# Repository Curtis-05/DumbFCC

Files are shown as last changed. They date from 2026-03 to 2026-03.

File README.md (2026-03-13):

<p align="center" width="100%">
  
</p>

<h1 align="center">Dumb FCC</h1>

<p align="center" width="100%">
  <a href="https://github.com/Curtis-05/DumbFCC/actions/workflows/ci.yaml">
    
  </a>
</p>

<p align="center" width="100%">
    
</p>

***

<p align="center">
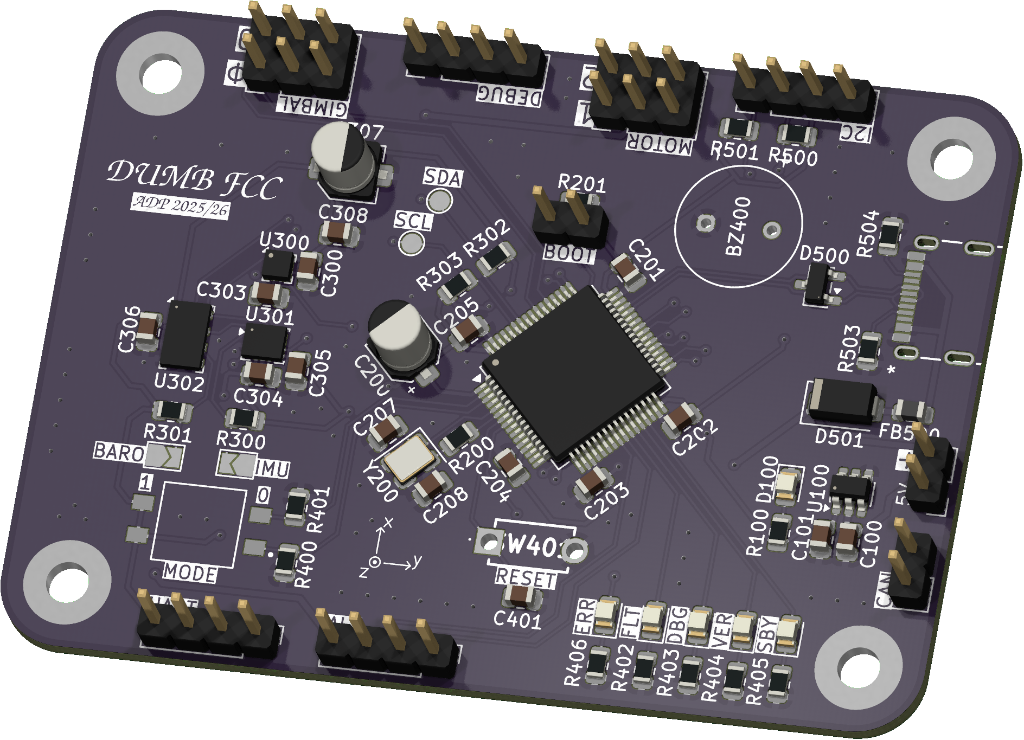
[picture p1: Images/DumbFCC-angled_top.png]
3D Top Angled
  
&nbsp; &nbsp; &nbsp; &nbsp;
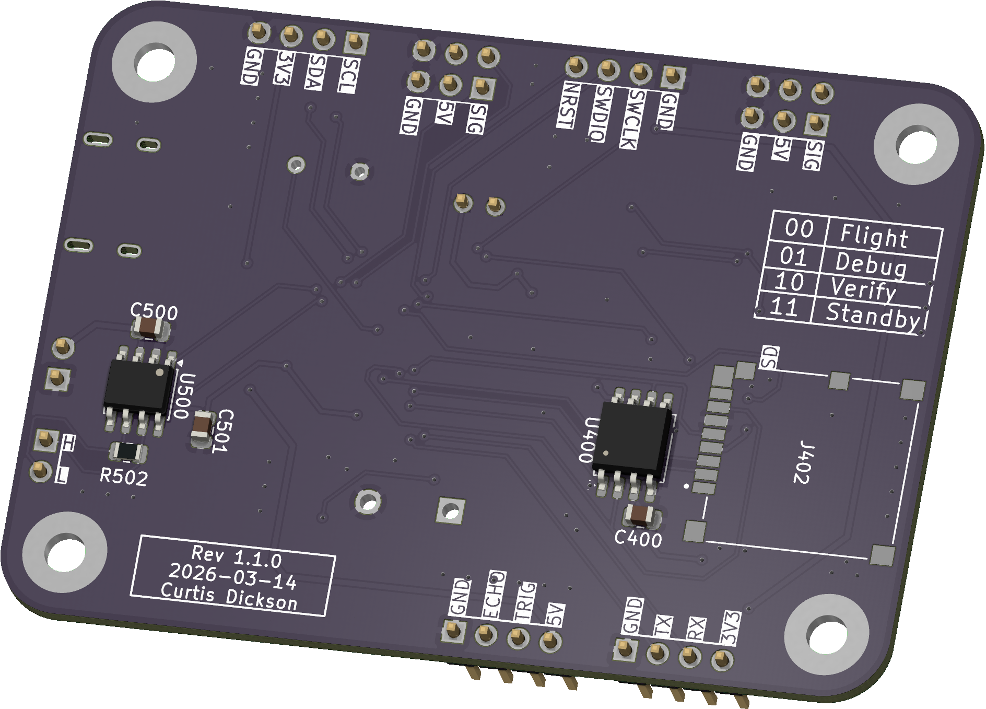
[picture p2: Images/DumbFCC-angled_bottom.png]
3D Bottom Angled
  
</p>

***

## SPECIFICATIONS

| Parameter | Value | 
| --- | --- |
| Dimensions | 70.0 × 50.0 mm |

***

## DIRECTORY STRUCTURE

    .
    ├─ Computations       # Misc calculations
    ├─ HTML               # HTML files for generated webpage
    ├─ Images             # Pictures and renders
    │
    ├─ kibot_resources    # External resources for KiBot
    │  ├─ colors          # Color theme for KiCad
    │  ├─ fonts           # Fonts used in the project
    │  ├─ scripts         # External scripts used with KiBot
    │  └─ templates       # Templates for KiBot generated reports
    │
    ├─ kibot_yaml         # KiBot YAML config files
    ├─ KiRI               # KiRI (PCB diff viewer) files
    │
    ├─ lib                # KiCad footprint and symbol libraries
    │  ├─ 3d_models       # Component 3D models
    │  ├─ lib_fp          # Footprint libraries
    │  └─ lib_sym         # Symbol libraries
    │
    ├─ Logos              # Logos
    │
    ├─ Manufacturing      # Assembly and fabrication documents
    │  ├─ Assembly        # Assembly documents (BoM, pos, notes)
    │  │
    │  └─ Fabrication     # Fabrication documents (ZIP, notes)
    │     ├─ Drill Tables # CSV drill tables
    │     └─ Gerbers      # Gerbers
    │
    ├─ Report             # Reports for ERC/DRC
    ├─ Schematic          # PDF of schematic
    ├─ Templates          # Title block templates
    ├─ Testing
    │  └─ Testpoints      # Testpoints tables      
    │
    └─ Variants           # Outputs for assembly variants

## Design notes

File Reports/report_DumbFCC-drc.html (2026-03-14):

Logo

(https://github.com/INTI-CMNB/KiBot/) | DRC report for DumbFCC
| PCB: DumbFCC Revision: 1.1.0 Date: 2026-03-14T05:20:28+0000 KiCad Version: 9.0.7 | Errors: 0 Warnings: 76 Total: 76

Violations

Type | Description | Details
connection_width | Copper connection too narrow (board setup constraints minimum connection width 0.1500 mm; actual 0.1209 mm) (L1 (Sig, PWR)) | @(114.5 mm, 60.0 mm): Zone 'GND' [GND] on L1 (Sig, PWR), L4 (Sig, PWR) and 2 more, priority 0
connection_width | Copper connection too narrow (board setup constraints minimum connection width 0.1500 mm; actual 0.1338 mm) (L1 (Sig, PWR)) | @(114.5 mm, 60.0 mm): Zone 'GND' [GND] on L1 (Sig, PWR), L4 (Sig, PWR) and 2 more, priority 0
connection_width | Copper connection too narrow (board setup constraints minimum connection width 0.1500 mm; actual 0.0480 mm) (L1 (Sig, PWR)) | @(114.5 mm, 60.0 mm): Zone 'GND' [GND] on L1 (Sig, PWR), L4 (Sig, PWR) and 2 more, priority 0
silk_edge_clearance | Silkscreen clipped by board edge | @(184.5 mm, 65.0 mm): Segment on Edge.Cuts @(184.161593 mm, 80.5974 mm): Segment of J506 on F.Silkscreen
silk_edge_clearance | Silkscreen clipped by board edge | @(184.5 mm, 65.0 mm): Segment on Edge.Cuts @(185.0052 mm, 71.4026 mm): Segment of J506 on F.Silkscreen
lib_footprint_mismatch | Footprint 'SOT-23-3' does not match copy in library 'Package_TO_SOT_SMD'. | @(171.3625 mm, 75.95 mm): Footprint D500
lib_footprint_mismatch | Footprint 'PinHeader_1x04_P2.54mm_Vertical' does not match copy in library 'Connector_PinHeader_2.54mm'. | @(134.81 mm, 108.0 mm): Footprint J501
lib_footprint_mismatch | Footprint 'C_0805_2012Metric' does not match copy in library 'Capacitor_SMD'. | @(141.3 mm, 90.9 mm): Footprint C207
lib_footprint_mismatch | Footprint 'C_0805_2012Metric' does not match copy in library 'Capacitor_SMD'. | @(122.2 mm, 85.0 mm): Footprint C306
lib_footprint_mismatch | Footprint 'PinHeader_2x03_P2.54mm_Vertical' does not match copy in library 'Connector_PinHeader_2.54mm'. | @(153.75 mm, 64.29 mm): Footprint J504
lib_footprint_mismatch | Footprint 'C_0805_2012Metric' does not match copy in library 'Capacitor_SMD'. | @(153.55 mm, 102.5 mm): Footprint C401
lib_footprint_mismatch | Footprint 'LED_0805_2012Metric' does not match copy in library 'LED_SMD'. | @(173.85 mm, 103.0 mm): Footprint D403
lib_footprint_mismatch | Footprint 'R_0805_2012Metric' does not match copy in library 'Resistor_SMD'. | @(176.0 mm, 80.5 mm): Footprint R503
lib_footprint_mismatch | Footprint 'R_0805_2012Metric' does not match copy in library 'Resistor_SMD'. | @(135.55 mm, 101.68 mm): Footprint R400
lib_footprint_mismatch | Footprint 'R_0805_2012Metric' does not match copy in library 'Resistor_SMD'. | @(173.85 mm, 106.9375 mm): Footprint R405
lib_footprint_mismatch | Footprint 'R_0805_2012Metric' does not match copy in library 'Resistor_SMD'. | @(163.3 mm, 64.5 mm): Footprint R501
lib_footprint_mismatch | Footprint 'Crystal_SMD_Abracon_ABM8G-4Pin_3.2x2.5mm' does not match copy in library 'Crystal'. | @(143.378858 mm, 92.823223 mm): Footprint Y200
lib_footprint_mismatch | Footprint 'LED_0805_2012Metric' does not match copy in library 'LED_SMD'. | @(167.14 mm, 103.0625 mm): Footprint D401
lib_footprint_mismatch | Footprint 'R_0805_2012Metric' does not match copy in library 'Resistor_SMD'. | @(135.56 mm, 97.32 mm): Footprint R401
lib_footprint_mismatch | Footprint 'LED_0805_2012Metric' does not match copy in library 'LED_SMD'. | @(171.8 mm, 91.7 mm): Footprint D100
lib_footprint_mismatch | Footprint 'PinHeader_1x04_P2.54mm_Vertical' does not match copy in library 'Connector_PinHeader_2.54mm'. | @(148.33 mm, 108.0 mm): Footprint J300
lib_footprint_mismatch | Footprint 'C_0805_2012Metric' does not match copy in library 'Capacitor_SMD'. | @(157.328249 mm, 93.171751 mm): Footprint C203
lib_footprint_mismatch | Footprint 'LED_0805_2012Metric' does not match copy in library 'LED_SMD'. | @(163.64 mm, 103.0625 mm): Footprint D400
lib_footprint_mismatch | Footprint 'C_0805_2012Metric' does not match copy in library 'Capacitor_SMD'. | @(133.8 mm, 86.8 mm): Footprint C305
lib_footprint_mismatch | Footprint 'R_0805_2012Metric' does not match copy in library 'Resistor_SMD'. | @(125.0 mm, 91.0 mm): Footprint R301
lib_footprint_mismatch | Footprint 'C_0805_2012Metric' does not match copy in library 'Capacitor_SMD'. | @(163.0 mm, 87.5 mm): Footprint C202
lib_footprint_mismatch | Footprint 'PinHeader_1x04_P2.54mm_Vertical' does not match copy in library 'Connector_PinHeader_2.54mm'. | @(164.19 mm, 61.75 mm): Footprint J502
lib_footprint_mismatch | Footprint 'C_0805_2012Metric' does not match copy in library 'Capacitor_SMD'. | @(133.3 mm, 79.0 mm): Footprint C300
lib_footprint_mismatch | Footprint 'R_0805_2012Metric' does not match copy in library 'Resistor_SMD'. | @(171.8 mm, 95.2625 mm): Footprint R100
lib_footprint_mismatch | Footprint 'PinHeader_1x02_P2.54mm_Vertical' does not match copy in library 'Connector_PinHeader_2.54mm'. | @(182.5 mm, 91.225 mm): Footprint J100
lib_footprint_mismatch | Footprint 'C_0805_2012Metric' does not match copy in library 'Capacitor_SMD'. | @(151.0 mm, 92.5 mm): Footprint C204
lib_footprint_mismatch | Footprint 'PinHeader_1x04_P2.54mm_Vertical' does not match copy in library 'Connector_PinHeader_2.54mm'. | @(139.21 mm, 61.75 mm): Footprint J500
lib_footprint_mismatch | Footprint 'SOT-23-6' does not match copy in library 'Package_TO_SOT_SMD'. | @(176.65 mm, 91.5375 mm): Footprint U100
lib_footprint_mismatch | Footprint 'C_0805_2012Metric' does not match copy in library 'Capacitor_SMD'. | @(131.1 mm, 87.5 mm): Footprint C304
lib_footprint_mismatch | Footprint 'R_0805_2012Metric' does not match copy in library 'Resistor_SMD'. | @(146.7 mm, 90.7 mm): Footprint R200
lib_footprint_mismatch | Footprint 'R_0805_2012Metric' does not match copy in library 'Resistor_SMD'. | @(167.7 mm, 64.5 mm): Footprint R500
lib_footprint_mismatch | Footprint 'R_0805_2012Metric' does not match copy in library 'Resistor_SMD'. | @(160.09 mm, 107.0 mm): Footprint R406
lib_footprint_mismatch | Footprint 'L_0805_2012Metric' does not match copy in library 'Inductor_SMD'. | @(180.1 mm, 85.0 mm): Footprint FB500
lib_footprint_mismatch | Footprint 'R_0805_2012Metric' does not match copy in library 'Resistor_SMD'. | @(167.1 mm, 107.0 mm): Footprint R403
lib_footprint_mismatch | Footprint 'C_0805_2012Metric' does not match copy in library 'Capacitor_SMD'. | @(146.0 mm, 82.5 mm): Footprint C205
lib_footprint_mismatch | Footprint 'R_0805_2012Metric' does not match copy in library 'Resistor_SMD'. | @(147.0 mm, 76.5 mm): Footprint R302
lib_footprint_mismatch | Footprint 'LED_0805_2012Metric' does not match copy in library 'LED_SMD'. | @(170.5 mm, 103.0625 mm): Footprint D402
lib_footprint_mismatch | Footprint 'R_0805_2012Metric' does not match copy in library 'Resistor_SMD'. | @(152.4125 mm, 71.5 mm): Footprint R201
lib_footprint_mismatch | Footprint 'C_0805_2012Metric' does not match copy in library 'Capacitor_SMD'. | @(175.1 mm, 95.4 mm): Footprint C101
lib_footprint_mismatch | Footprint 'C_0805_2012Metric' does not match copy in library 'Capacitor_SMD'. | @(177.1 mm, 95.4 mm): Footprint C100
lib_footprint_mismatch | Footprint 'C_0805_2012Metric' does not match copy in library 'Capacitor_SMD'. | @(145.4 mm, 94.8 mm): Footprint C208
lib_footprint_mismatch | Footprint 'LQFP-64_10x10mm_P0.5mm' does not match copy in library 'Package_QFP'. | @(154.5 mm, 85.0 mm): Footprint U200
lib_footprint_mismatch | Footprint 'C_0805_2012Metric' does not match copy in library 'Capacitor_SMD'. | @(130.6 mm, 81.3 mm): Footprint C303
lib_footprint_mismatch | Footprint 'R_0805_2012Metric' does not match copy in library 'Resistor_SMD'. | @(176.0 mm, 71.5 mm): Footprint R504
lib_footprint_mismatch | Footprint 'C_0805_2012Metric' does not match copy in library 'Capacitor_SMD'. | @(157.0 mm, 76.5 mm): Footprint C201
lib_footprint_mismatch | Footprint 'LED_0805_2012Metric' does not match copy in library 'LED_SMD'. | @(160.09 mm, 103.0625 mm): Footprint D404
lib_footprint_mismatch | Footprint 'LGA-14_3x2.5mm_P0.5mm_LayoutBorder3x4y' does not match copy in library 'Package_LGA'. | @(131.0 mm, 85.0 mm): Footprint U301
lib_footprint_mismatch | Footprint 'PinHeader_2x03_P2.54mm_Vertical' does not match copy in library 'Connector_PinHeader_2.54mm'. | @(127.46 mm, 64.29 mm): Footprint J505
lib_footprint_mismatch | Footprint 'R_0805_2012Metric' does not match copy in library 'Resistor_SMD'. | @(163.64 mm, 107.0 mm): Footprint R402
lib_footprint_mismatch | Footprint 'R_0805_2012Metric' does not match copy in library 'Resistor_SMD'. | @(144.5 mm, 79.0 mm): Footprint R303
lib_footprint_mismatch | Footprint 'PinHeader_1x02_P2.54mm_Vertical' does not match copy in library 'Connector_PinHeader_2.54mm'. | @(182.5 mm, 96.225 mm): Footprint J503
lib_footprint_mismatch | Footprint 'R_0805_2012Metric' does not match copy in library 'Resistor_SMD'. | @(170.5 mm, 107.0625 mm): Footprint R404
lib_footprint_mismatch | Footprint 'C_0805_2012Metric' does not match copy in library 'Capacitor_SMD'. | @(135.0 mm, 76.0 mm): Footprint C308
lib_footprint_mismatch | Footprint 'R_0805_2012Metric' does not match copy in library 'Resistor_SMD'. | @(130.5 mm, 91.0 mm): Footprint R300
lib_footprint_mismatch | Footprint 'SOIC-8_5.3x5.3mm_P1.27mm' does not match copy in library 'Package_SO'. | @(137.0 mm, 91.5 mm): Footprint U400
lib_footprint_mismatch | Footprint 'SOIC-8_3.9x4.9mm_P1.27mm' does not match copy in library 'Package_SO'. | @(175.905 mm, 91.475 mm): Footprint U500
lib_footprint_mismatch | Footprint 'R_0805_2012Metric' does not match copy in library 'Resistor_SMD'. | @(176.0 mm, 96.5 mm): Footprint R502
lib_footprint_mismatch | Footprint 'C_0805_2012Metric' does not match copy in library 'Capacitor_SMD'. | @(135.4 mm, 97.3 mm): Footprint C400
lib_footprint_mismatch | Footprint 'C_0805_2012Metric' does not match copy in library 'Capacitor_SMD'. | @(170.5 mm, 94.0 mm): Footprint C501
lib_footprint_mismatch | Footprint 'C_0805_2012Metric' does not match copy in library 'Capacitor_SMD'. | @(176.0 mm, 86.5 mm): Footprint C500
silk_over_copper | Silkscreen clipped by solder mask | @(129.9 mm, 78.4 mm): Segment of U300 on F.Silkscreen
silk_over_copper | Silkscreen clipped by solder mask | @(129.9 mm, 79.6 mm): Segment of U300 on F.Silkscreen
silk_over_copper | Silkscreen clipped by solder mask | @(129.9 mm, 80.1 mm): Segment of U300 on F.Silkscreen
silk_over_copper | Silkscreen clipped by solder mask | @(132.1 mm, 77.9 mm): Segment of U300 on F.Silkscreen
silk_over_copper | Silkscreen clipped by solder mask | @(132.1 mm, 78.4 mm): Segment of U300 on F.Silkscreen
silk_over_copper | Silkscreen clipped by solder mask | @(132.1 mm, 79.6 mm): Segment of U300 on F.Silkscreen
silk_over_copper | Silkscreen clipped by solder mask | @(178.1968 mm, 76.0 mm): Reference field of J506
silk_over_copper | Silkscreen clipped by solder mask | @(123.4225 mm, 87.7225 mm): Segment of U302 on F.Silkscreen
silk_over_copper | Silkscreen clipped by solder mask | @(126.7225 mm, 82.5225 mm): Segment of U302 on F.Silkscreen
silk_over_copper | Silkscreen clipped by solder mask | @(126.7225 mm, 87.2225 mm): Segment of U302 on F.Silkscreen
silk_over_copper | Silkscreen clipped by solder mask | @(153.55 mm, 98.3533 mm): Reference field of SW401

Generated by KiBot (https://github.com/INTI-CMNB/KiBot/) v1.8.6

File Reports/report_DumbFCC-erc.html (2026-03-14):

Logo

(https://github.com/INTI-CMNB/KiBot/) | ERC report for DumbFCC
| Schematic: DumbFCC Revision: 1.1.0 Date: 2026-03-14T05:20:26+0000 KiCad Version: 9.0.7 | Errors: 0 Warnings: 13 Total: 13

Sheet / (DumbFCC.kicad_sch)

Type | Description | Details
footprint_link_issues | The current configuration does not include the footprint library '5027740891'. | @(0.6223 mm, 0.7112 mm): Symbol J402 [5027740891]
lib_symbol_issues | The current configuration does not include the symbol library '5027740891' | @(0.6223 mm, 0.7112 mm): Symbol J402 [5027740891]
footprint_link_issues | The current configuration does not include the footprint library 'AI-1027-TWT-3V-R'. | @(1.1938 mm, 1.0922 mm): Symbol BZ400 [Buzzer]
footprint_link_issues | The current configuration does not include the footprint library 'DS04-254-1-02BK-SMT'. | @(1.6002 mm, 0.6096 mm): Symbol SW400 [SW_DIP_x02]
footprint_link_issues | The current configuration does not include the footprint library 'DTS-32N-V-B'. | @(1.5748 mm, 1.143 mm): Symbol SW401 [SW_Push]
footprint_link_issues | The current configuration does not include the footprint library '2171790001_MOL'. | @(1.7018 mm, 1.0922 mm): Symbol J506 [2171790001]
lib_symbol_issues | The current configuration does not include the symbol library '2026-01-15_13-06-23' | @(1.7018 mm, 1.0922 mm): Symbol J506 [2171790001]
lib_symbol_issues | The current configuration does not include the symbol library 'MCP2562T-E_SN' | @(2.2987 mm, 0.6223 mm): Symbol U500 [MCP2562T-E_SN]
footprint_link_issues | Footprint 'P25_DO-214AC_SMA' not found in library 'DO214AAC'. | @(2.3495 mm, 1.1557 mm): Symbol D501 [D_Schottky]
lib_symbol_issues | The current configuration does not include the symbol library 'ADP3330ARTZ3.3-RL7' | @(1.4351 mm, 0.9271 mm): Symbol U100 [ADP3330ARTZ3.3-RL7]
lib_symbol_mismatch | Symbol 'Crystal_GND23' doesn't match copy in library 'Device' | @(2.4638 mm, 0.889 mm): Symbol Y200 [Crystal_GND23]

Sheet /Project Architecture/Sensors/ (Sensors.kicad_sch)

Type | Description | Details
pin_to_pin | Pins of type Bidirectional and Power output are connected | @(1.1557 mm, 0.8001 mm): Symbol U301 Pin 2 [SDX, Bidirectional, Line] @(2.1082 mm, 1.0922 mm): Symbol J506 Pin B1/A12 [GND, Power output, Line]

Sheet /Project Architecture/Connections/ (Connections.kicad_sch)

Type | Description | Details
multiple_net_names | Both I2C_PERIPH_SCL and I2C_SCL are attached to the same items; I2C_PERIPH_SCL will be used in the netlist | @(1.3081 mm, 0.5715 mm): Label 'I2C_PERIPH_SCL' @(1.3081 mm, 0.5715 mm): Label 'I2C_SCL'

Generated by KiBot (https://github.com/INTI-CMNB/KiBot/) v1.8.6

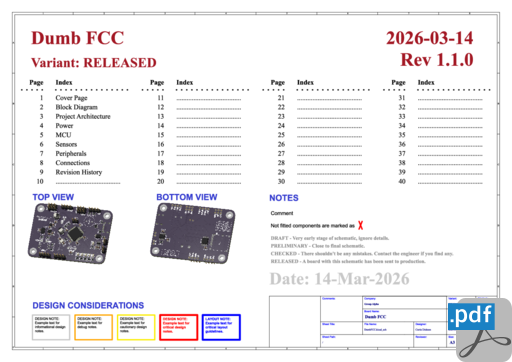
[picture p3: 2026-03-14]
HTML/images/cat_pdf_schematic_DumbFCC-schematic.png

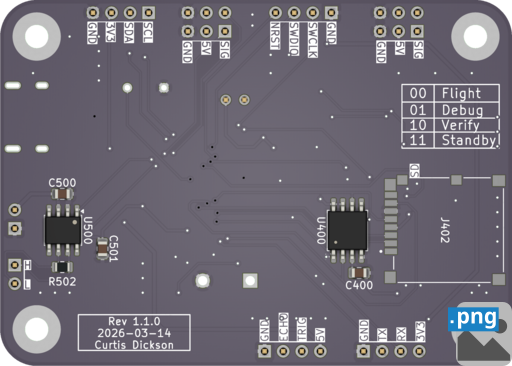
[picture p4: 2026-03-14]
HTML/images/cat_png_3d_viewer_bottom_DumbFCC-bottom.png

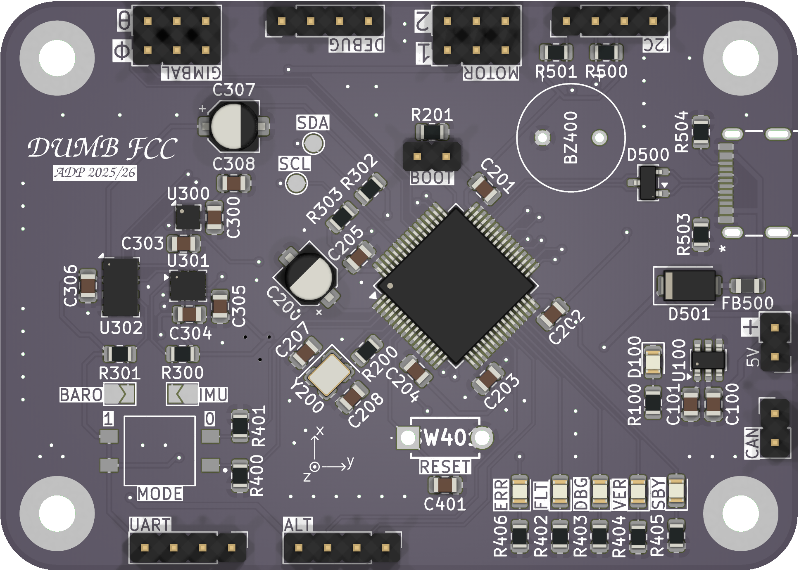
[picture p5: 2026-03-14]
Images/DumbFCC-top.png

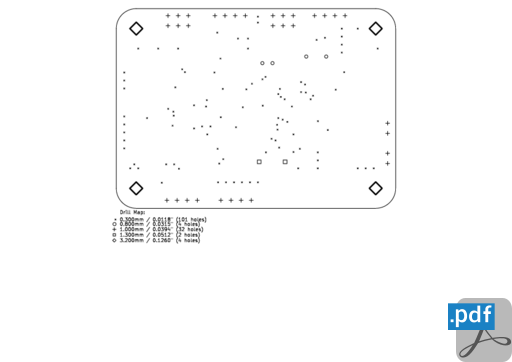
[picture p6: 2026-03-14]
HTML/images/cat_pdf_drill_map_DumbFCC-PTH_drill_map.png

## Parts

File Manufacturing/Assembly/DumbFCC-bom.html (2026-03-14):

 | Bill of Materials
 | Schematic: DumbFCC Variant: RELEASED Revision: 1.1.0 Date: 2025-01-12 KiCad Version: 9.0.7+1 | Component Groups: 33 Component Count: 70 (per PCB) Fitted Components: 70 (per PCB) Number of PCBs: 1 Total Components: 70 (for 1 PCBs)
Row | Quantity Per PCB | References | Value | Datasheet | Footprint | Description | Manufacturer | Manufacturer Part Number | Supplier Part Number
1 | 1 | BZ400 | Buzzer | ~ | XDCR_AI-1027-TWT-3V-R | Buzzer, polarized
2 | 2 | C207 C208 | 10p | ~ | C_0805_2012Metric | Unpolarized capacitor
3 | 14 | C201 C202 C203 C204 C205 C300 C304 C305 C306 C308 C400 C401 C500 C501 | 100n | ~ | C_0805_2012Metric | Unpolarized capacitor
4 | 1 | C303 | 220n | ~ | C_0805_2012Metric | Unpolarized capacitor
5 | 2 | C100 C101 | 470n | ~ | C_0805_2012Metric | Unpolarized capacitor
6 | 2 | C200 C307 | 10u | ~ | CP_Elec_4x5.7 | Polarized capacitor
7 | 1 | D401 | DBG | ~ | LED_0805_2012Metric | Light emitting diode
8 | 1 | D501 | D_Schottky | ~ | P25_DO-214AC_SMA | Schottky diode
9 | 1 | D404 | ERR | ~ | LED_0805_2012Metric | Light emitting diode
10 | 1 | D500 | ESDA6V1l-tp | https://www.st.com/resource/en/datasheet/esdal.pdf | SOT-23-3 | TVS Diode Array, 5.5V Standoff, 2 Channels, SOT23
11 | 1 | D400 | FLT | ~ | LED_0805_2012Metric | Light emitting diode
12 | 1 | D100 | PWR | ~ | LED_0805_2012Metric | Light emitting diode
13 | 1 | D403 | SBY | ~ | LED_0805_2012Metric | Light emitting diode
14 | 1 | D402 | VER | ~ | LED_0805_2012Metric | Light emitting diode
15 | 1 | FB500 | FerriteBead | ~ | L_0805_2012Metric | Ferrite bead
16 | 8 | J100 J300 J500 J501 J502 J503 J504 J505 | 5V Input | ~ | PinHeader_1x02_P2.54mm_Vertical | Generic connector, single row, 01x02, script generated Generic connector, single row, 01x04, script generated Generic connector, double row, 02x03, counter clockwise pin numbering scheme (similar to DIP package numbering), script generated (kicad-library-utils/schlib/autogen/connector/)
17 | 1 | J402 | SD port |  | MOLEX_5027740891
18 | 1 | J506 | USB C | https://www.molex.com/en-us/products/part-detail-pdf/2171790001?display=pdf | 2171790001_MOL
19 | 1 | R502 | 120 | ~ | R_0805_2012Metric | Resistor
20 | 6 | R100 R402 R403 R404 R405 R406 | 330 | ~ | R_0805_2012Metric | Resistor
21 | 1 | R200 | 620 | ~ | R_0805_2012Metric | Resistor
22 | 2 | R503 R504 | 5k1 | ~ | R_0805_2012Metric | Resistor
23 | 9 | R201 R300 R301 R302 R303 R400 R401 R500 R501 | 10k | ~ | R_0805_2012Metric | Resistor
24 | 1 | SW400 | Mode Switch | ~ | SW_DS04-254-1-02BK-SMT | 2x DIP Switch, Single Pole Single Throw (SPST) switch, small symbol
25 | 1 | SW401 | Reset | ~ | DTS32NVB | Push button switch, generic, two pins
26 | 1 | U100 | ADP3330ARTZ3.3-RL7 |  | SOT-23-6
27 | 1 | U300 | LIS2MDL | https://www.st.com/resource/en/datasheet/lis2mdl.pdf | LGA-12_2x2mm_P0.5mm | Ultra-low-power, 3-axis digital output magnetometer, LGA-12
28 | 1 | U301 | LSM6DSL | https://www.st.com/resource/en/datasheet/lsm6dsl.pdf | LGA-14_3x2.5mm_P0.5mm_LayoutBorder3x4y | I2C/SPI, iNEMO inertial module: always-on 3D accelerometer and 3D gyroscope, 1.71V to 3.6V VCC
29 | 1 | U500 | MCP2562T-E_SN | https://www.snapeda.com/parts/MCP2562T-E/SN/Microchip/datasheet/ | SOIC-8_3.9x4.9mm_P1.27mm |  | Microchip
30 | 1 | U302 | MS5607-02BA | https://www.te.com/commerce/DocumentDelivery/DDEController?Action=showdoc | LGA-8_3x5mm_P1.25mm | Barometric pressure sensor, 20cm resolution, 10 to 1200 mbar, I2C and SPI interface up to 20MHz, LGA-8
31 | 1 | U400 | SST26VF064BT-104I/SM | http://ww1.microchip.com/downloads/en/DeviceDoc/20005045C.pdf | SOIC-8_5.3x5.3mm_P1.27mm | 8-Mbit, 2.7 to 3.6V, SPI Flash Memory, SOIC-8
32 | 1 | U200 | STM32H573RIT6 | https://www.st.com/resource/en/datasheet/stm32h573ri.pdf | LQFP-64_10x10mm_P0.5mm | STMicroelectronics Arm Cortex-M33 MCU, 2048KB flash, 640KB RAM, 250 MHz, 1.62-3.6V, 49 GPIO, LQFP64
33 | 1 | Y200 | 25MHz | ~ | Crystal_SMD_Abracon_ABM8G-4Pin_3.2x2.5mm | Four pin crystal, GND on pins 2 and 3
Color reference for columns:
KiCad Fields (default)
Generated Fields
User Fields
Empty Fields

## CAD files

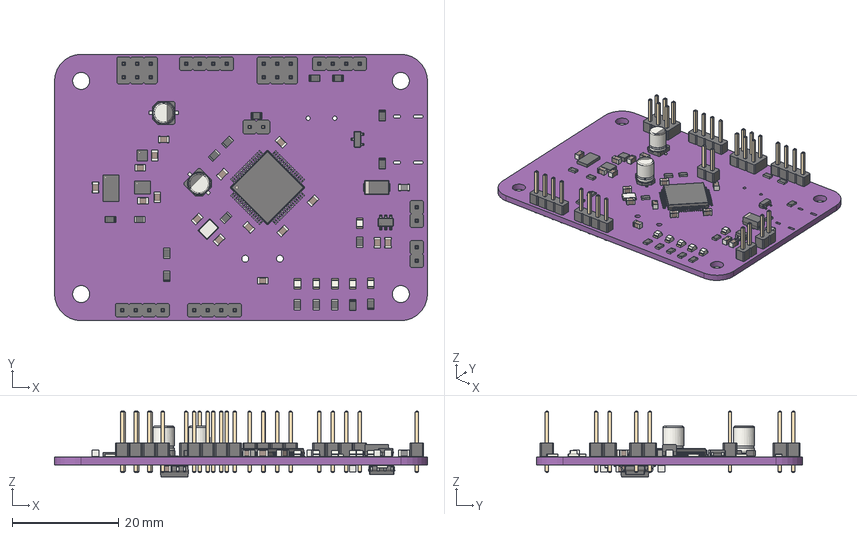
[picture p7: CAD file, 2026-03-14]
3D/DumbFCC.step
70.0 x 50.0 x 12.4 mm
SOT-23-3
PinHeader_1x04_P2.54mm_Vertical x 4
C_0805_2012Metric x 19
PinHeader_2x03_P2.54mm_Vertical x 2
D_SMA
LED_0805_2012Metric x 6
R_0805_2012Metric x 19
Crystal_SMD_Abracon_ABM8G-4Pin_3.2x2.5mm
LGA-12_2x2mm_P0.5mm
PinHeader_1x02_P2.54mm_Vertical x 3
SOT-23-6
L_0805_2012Metric
LGA-8_3x5mm_P1.25mm
LQFP-64_10x10mm_P0.5mm
LGA-14_3x2.5mm_P0.5mm_LayoutBorder3x4y
CP_Elec_4x5.7 x 2
SOIC-8_5.3x5.3mm_P1.27mm
SOIC-8_3.9x4.9mm_P1.27mm
kibot_xloh8s3n_PCB

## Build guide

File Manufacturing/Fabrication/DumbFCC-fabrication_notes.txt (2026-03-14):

FABRICATION NOTES (UNLESS OTHERWISE SPECIFIED)

1)	FABRICATE PER IPC-6012A CLASS 2.

2)	OUTLINE DEFINED IN SEPARATE GERBER FILE WITH
	"Edge_Cuts.GBR" SUFFIX.

	DIMENSIONS OF CIRCUMSIZED RECTANGLE SHOWN ON THIS
	DRAWING FOR REFERENCE ONLY.

3)	SEE SEPARATE DRILL FILES WITH ".DRL" SUFFIX 
	FOR HOLE LOCATIONS.

	SELECTED HOLE LOCATIONS SHOWN ON THIS DRAWING 
	FOR REFERENCE ONLY.

4)	SURFACE FINISH: HAL SNPB

5)	SOLDERMASK ON BOTH SIDES OF THE BOARD SHALL 
	BE LPI, COLOR PURPLE.

6)	SILK SCREEN LEGEND TO BE APPLIED PER LAYER 
	STACKUP USING WHITE NON-CONDUCTIVE EPOXY INK.

7)	ALL VIAS ARE TENTED ON BOTH SIDES UNLESS 
	SOLDERMASK OPENED IN GERBER.

8)	VENDOR SHOULD FOLLOW ROHS COMPLIANT PROCESS 
	AND Pb FREE FOR MANUFACTURING

9)	PCB MATERIAL REQUIREMENTS:

	A.	FLAMMABILITY RATING MUST MEET OR EXCEED 
		UL94V-0 REQUIREMENTS.
	B.	Tg 170 C OR EQUIVALENT.
	C.	EQUIVALENT MATERIAL SHALL BE RoHS COMPLIANT, 
		HALOGEN FREE AND APPROVED BY GROUP ALPHA.

10)	DESIGN GEOMETRY MINIMUM FEATURE SIZES:

	BOARD SIZE				70.000 × 50.000 mm
	BOARD THICKNESS		1.600 mm
	TRACE WIDTH			0.150 mm
	TRACE TO TRACE		0.150 mm
	MIN. HOLE (PTH)			0.300 mm
	MIN. HOLE (NPTH)		0.600 mm
	ANNULAR RING			0.150 mm
	COPPER TO HOLE		0.300 mm
	COPPER TO EDGE		0.500 mm
	HOLE TO HOLE			0.250 mm

11)	REFER TO IMPEDANCE TABLE FOR IMPEDANCE CONTROL REQUIREMENTS.

12)	CONFIRM SPACE WIDTHS AND SPACINGS.

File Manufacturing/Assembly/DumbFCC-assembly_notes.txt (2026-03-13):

ASSEMBLY NOTES (UNLESS OTHERWISE SPECIFIED)

1)	DO NOT POPULATE PARTS ARE MARKED WITH A RED CROSS.

2)	DO NOT POPULATE PARTS ARE NOT PRESENT IN THE BOM.

3)	IF CONFLICTING INFORMATION IS FOUND BETWEEN THE ASSEMBLY
	FILE AND BOM, BOM SHOULD BE USED AS THE MAIN SOURCE.

4)	CONFORMAL COATING IS NOT REQUIRED.

5)	DOT IDENTIFIES PIN #1 LOCATION AND DEVICE ORIENTATION
	WHEN VIEWED FROM THE TOP.

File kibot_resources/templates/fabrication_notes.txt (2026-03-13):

FABRICATION NOTES (UNLESS OTHERWISE SPECIFIED)

1)	FABRICATE PER IPC-6012A CLASS 2.

2)	OUTLINE DEFINED IN SEPARATE GERBER FILE WITH
	"Edge_Cuts.GBR" SUFFIX.

	DIMENSIONS OF CIRCUMSIZED RECTANGLE SHOWN ON THIS
	DRAWING FOR REFERENCE ONLY.

3)	SEE SEPARATE DRILL FILES WITH ".DRL" SUFFIX 
	FOR HOLE LOCATIONS.

	SELECTED HOLE LOCATIONS SHOWN ON THIS DRAWING 
	FOR REFERENCE ONLY.

4)	SURFACE FINISH: ${pcb_finish_cap}

5)	SOLDERMASK ON BOTH SIDES OF THE BOARD SHALL 
	BE LPI, COLOR ${solder_mask_color_text_cap}.

6)	SILK SCREEN LEGEND TO BE APPLIED PER LAYER 
	STACKUP USING ${silk_screen_color_text_cap} NON-CONDUCTIVE EPOXY INK.

7)	ALL VIAS ARE TENTED ON BOTH SIDES UNLESS 
	SOLDERMASK OPENED IN GERBER.

8)	VENDOR SHOULD FOLLOW ROHS COMPLIANT PROCESS 
	AND Pb FREE FOR MANUFACTURING

9)	PCB MATERIAL REQUIREMENTS:

	A.	FLAMMABILITY RATING MUST MEET OR EXCEED 
		UL94V-0 REQUIREMENTS.
	B.	Tg 170 C OR EQUIVALENT.
	C.	EQUIVALENT MATERIAL SHALL BE RoHS COMPLIANT, 
		HALOGEN FREE AND APPROVED BY ${COMPANY_cap}.

10)	DESIGN GEOMETRY MINIMUM FEATURE SIZES:

	BOARD SIZE				${bb_w_mm} × ${bb_h_mm} mm
	BOARD THICKNESS		${thickness_mm} mm
	TRACE WIDTH			${track_mm} mm
	TRACE TO TRACE		${clearance_mm} mm
	MIN. HOLE (PTH)			${drill_pth_real_mm} mm
	MIN. HOLE (NPTH)		${drill_npth_real_mm} mm
	ANNULAR RING			${oar_mm} mm
	COPPER TO HOLE		${c2h_mm} mm
	COPPER TO EDGE		${c2e_mm} mm
	HOLE TO HOLE			${h2h_mm} mm
#?stackup and impedance_controlled

#?stackup and impedance_controlled
11)	REFER TO IMPEDANCE TABLE FOR IMPEDANCE CONTROL REQUIREMENTS.
#?stackup and impedance_controlled

#?stackup and impedance_controlled
12)	CONFIRM SPACE WIDTHS AND SPACINGS.

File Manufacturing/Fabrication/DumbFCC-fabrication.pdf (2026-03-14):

# Top Fabrication (Scale 1:1)

# Dumb FCC Fabrication Document

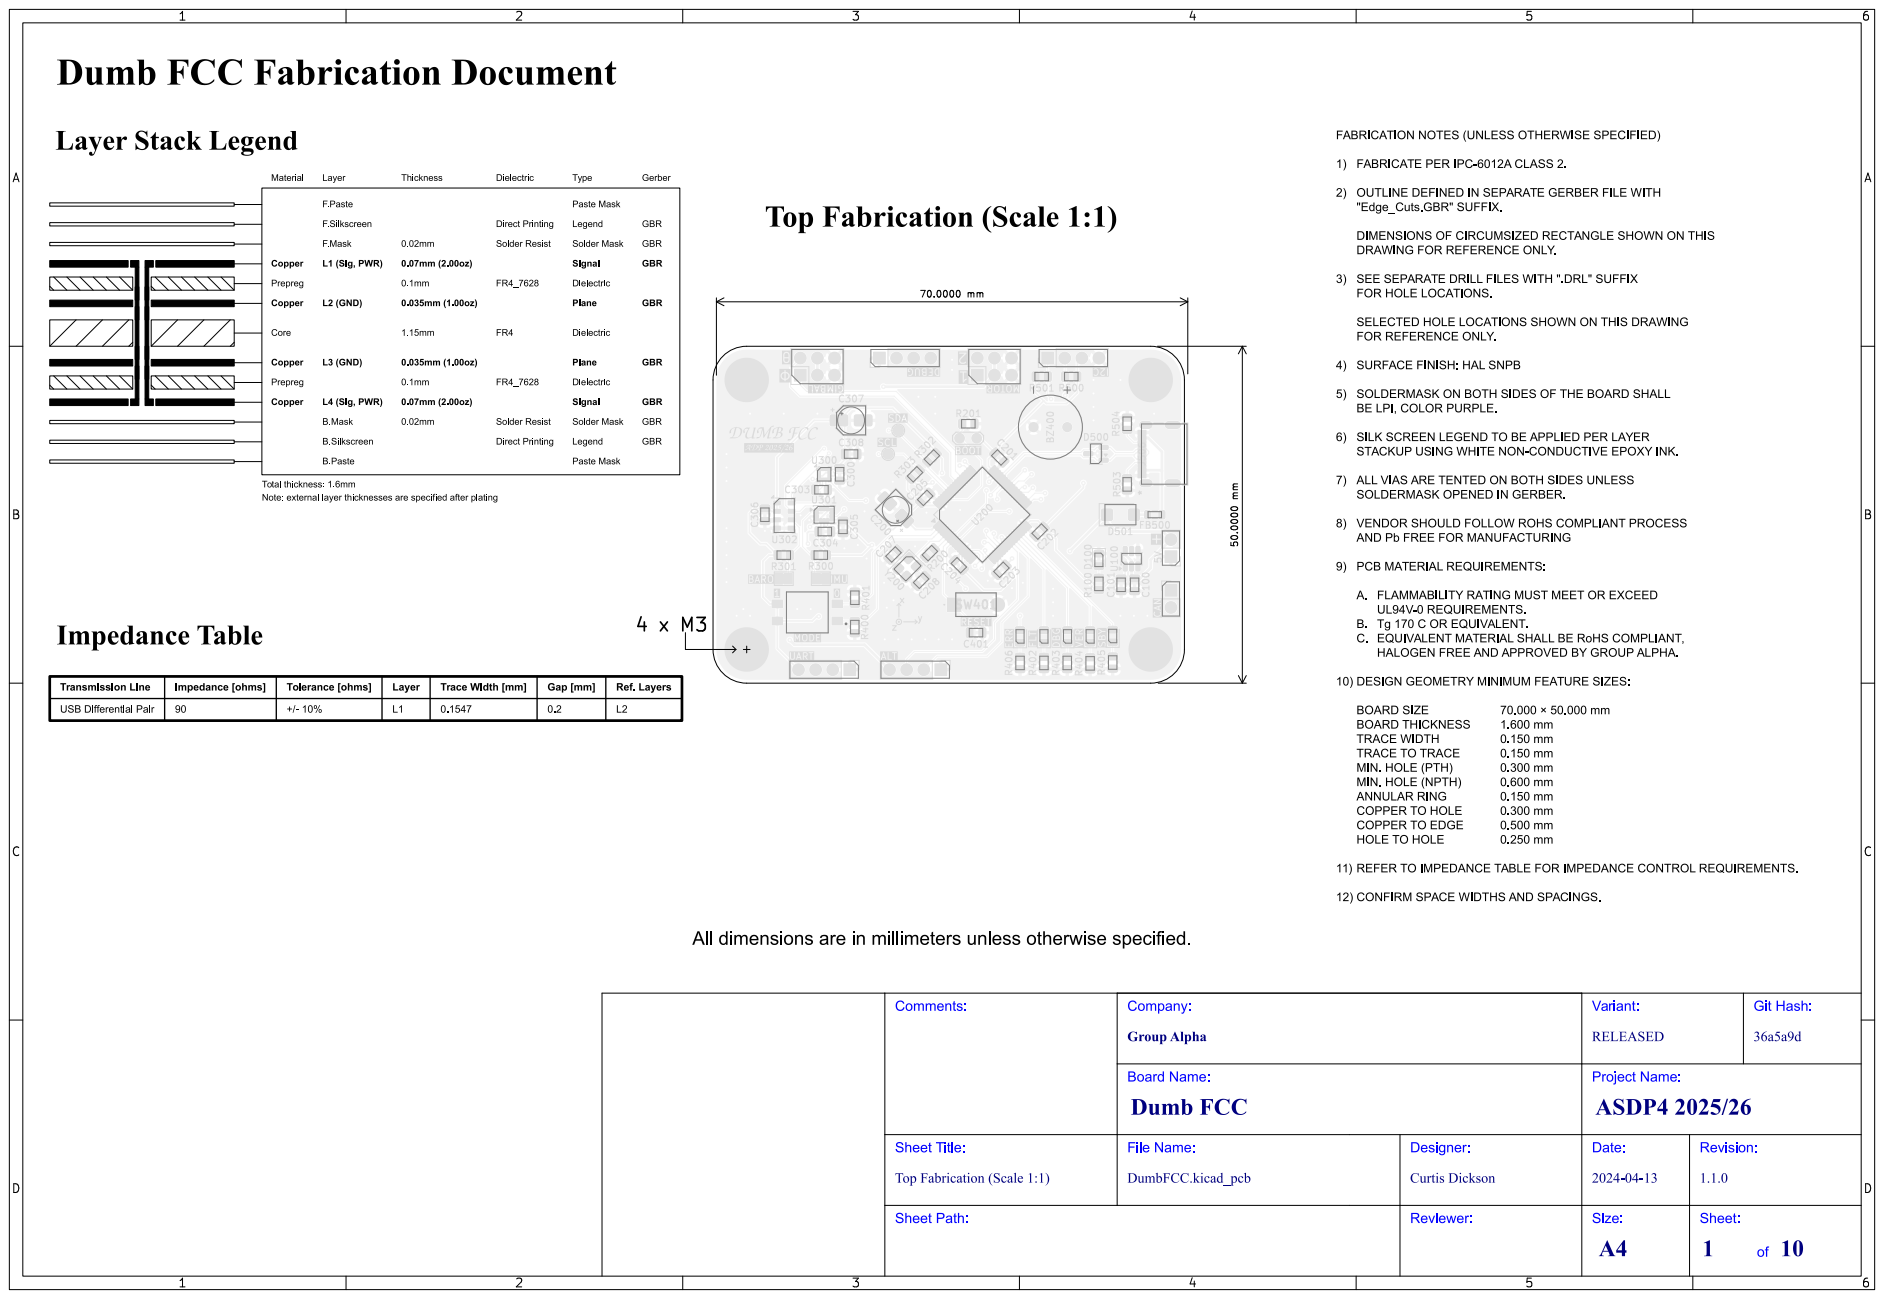
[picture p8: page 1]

# Bottom Fabrication (Scale 1:1)

# Dumb FCC Fabrication Document

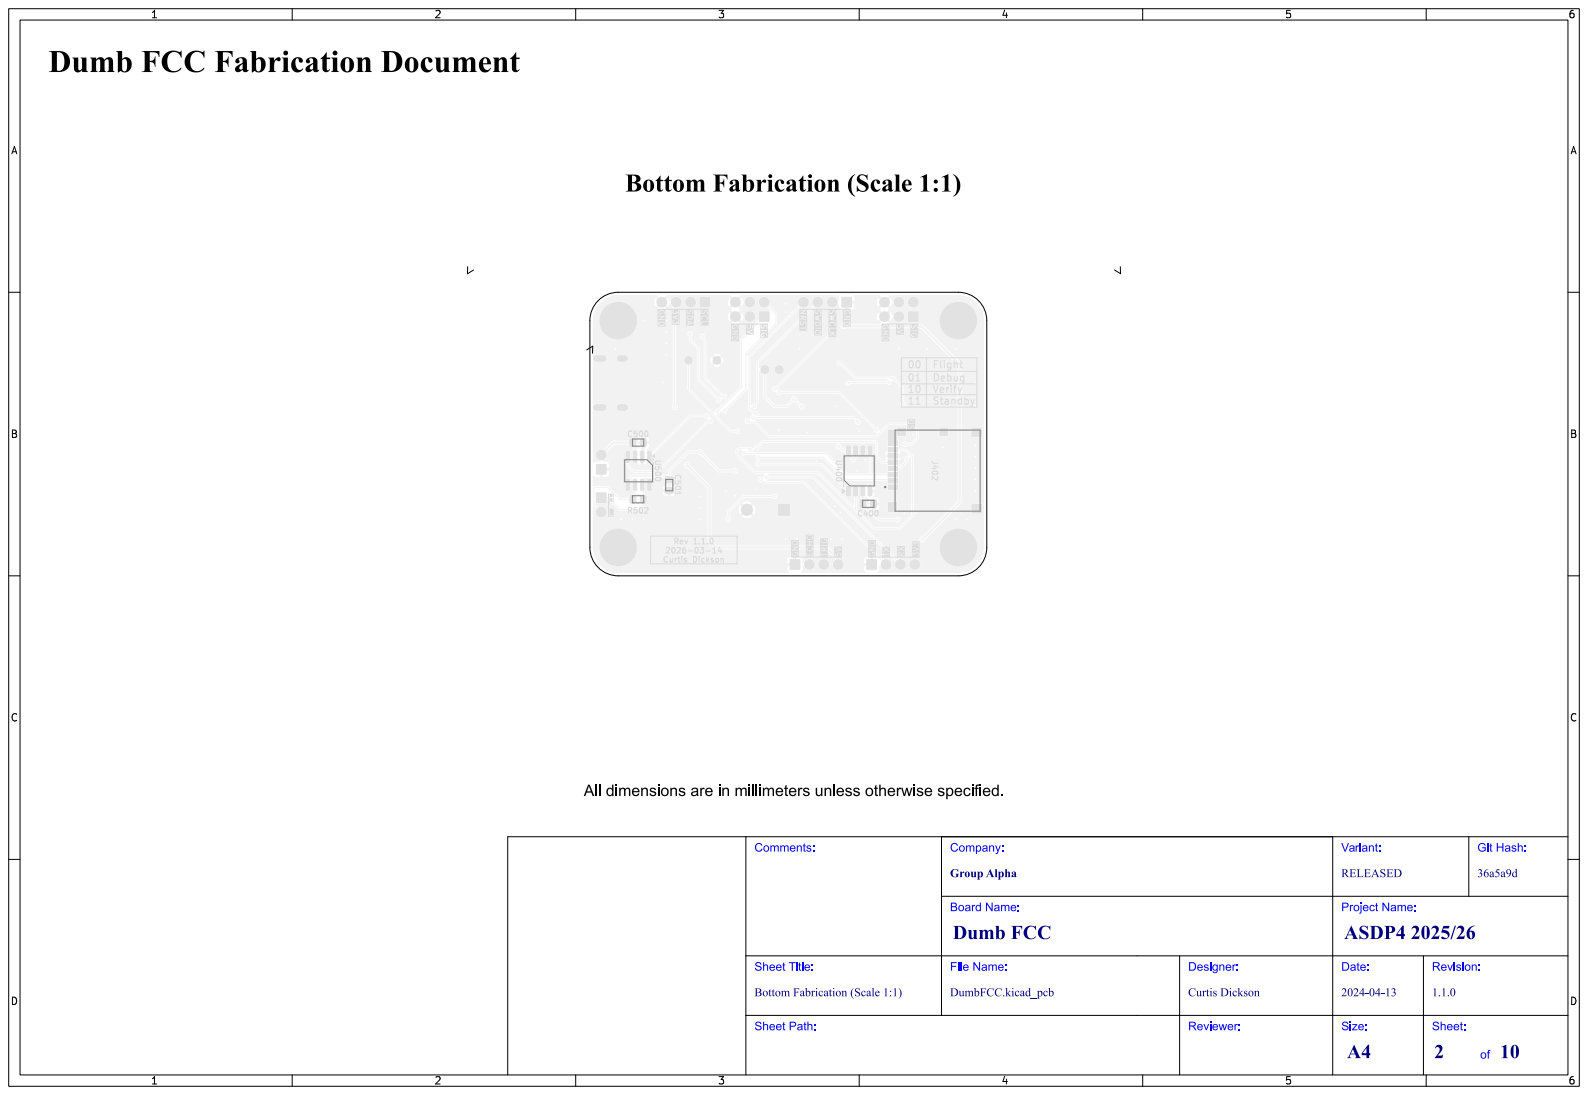
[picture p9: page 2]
Git; Hash:; Comments:; Sheet Path:; Sheet Title:; File Name:; Dumb FCC; ASDP4 2025/26; Group Alpha; Company:; RELEASED; Variant:; Board Name:; DumbFCC.kicad_pcb; Curtis Dickson; Designer:; Reviewer:; Project Name:; Date:; Revision:; Size:; Sheet:; Rev 1.1.0

00 | Flight
01 | Debug
10 | Verify
11 | Standby

Bottom Fabrication (Scale 1:1)

# Drill Drawing L1 - L4 (Scale 1:1)

# Dumb FCC Fabrication Document

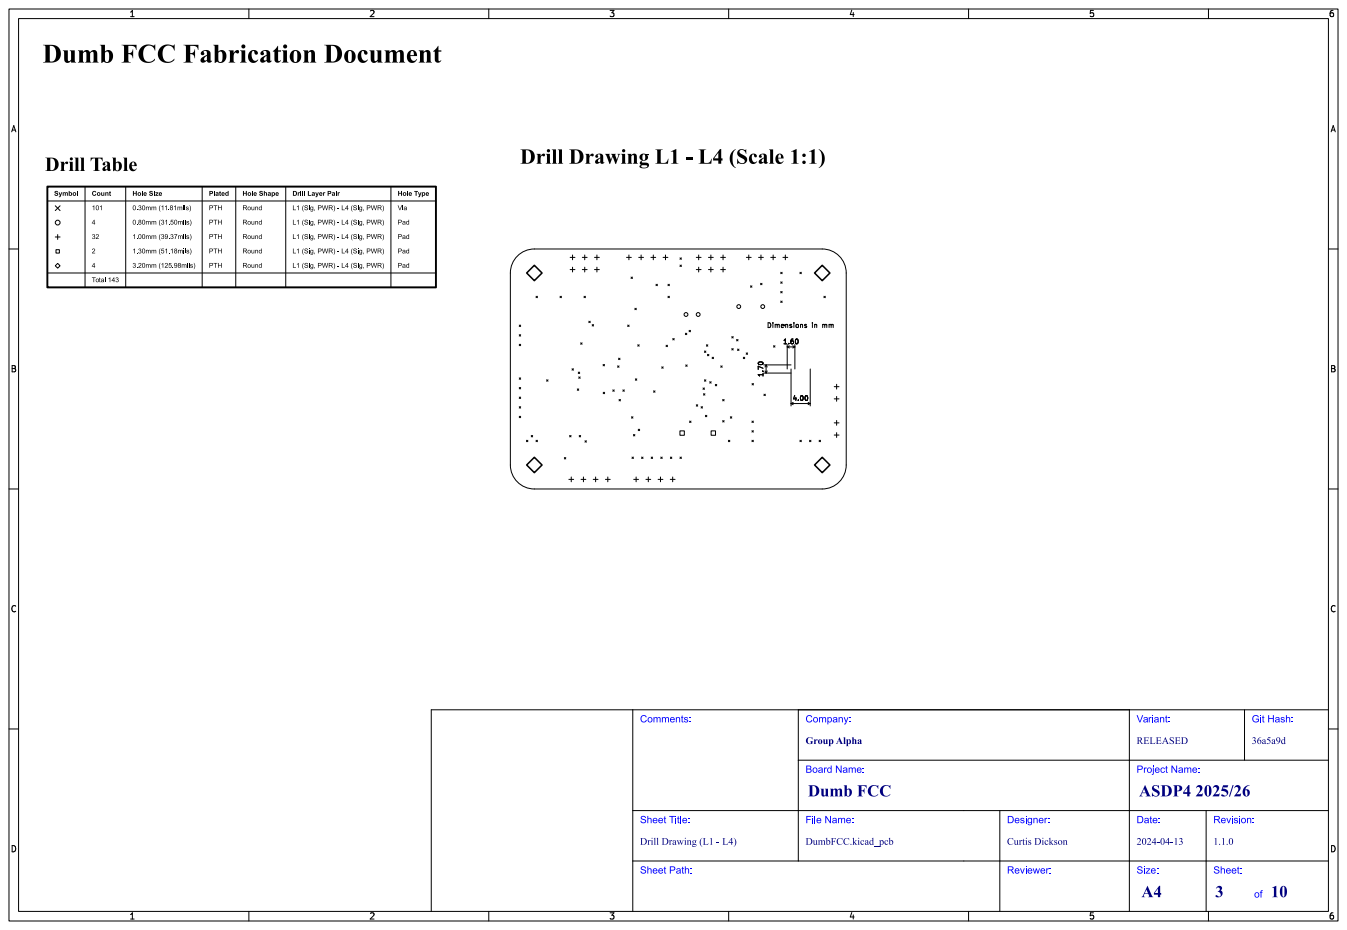
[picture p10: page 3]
Git; Hash:; Comments:; Drill Drawing (L1 - L4); Sheet Path:; Sheet Title:; File Name:; Dumb FCC; ASDP4 2025/26; Group Alpha; Company:; RELEASED; Variant:; Board Name:; DumbFCC.kicad_pcb; Curtis Dickson; Designer:; Reviewer:; Project Name:; Date:; Revision:; Size:; Sheet:

Dimensions in mm

# Drill Drawing L1 - L4 (Scale 1:1)

# Dumb FCC Fabrication Document

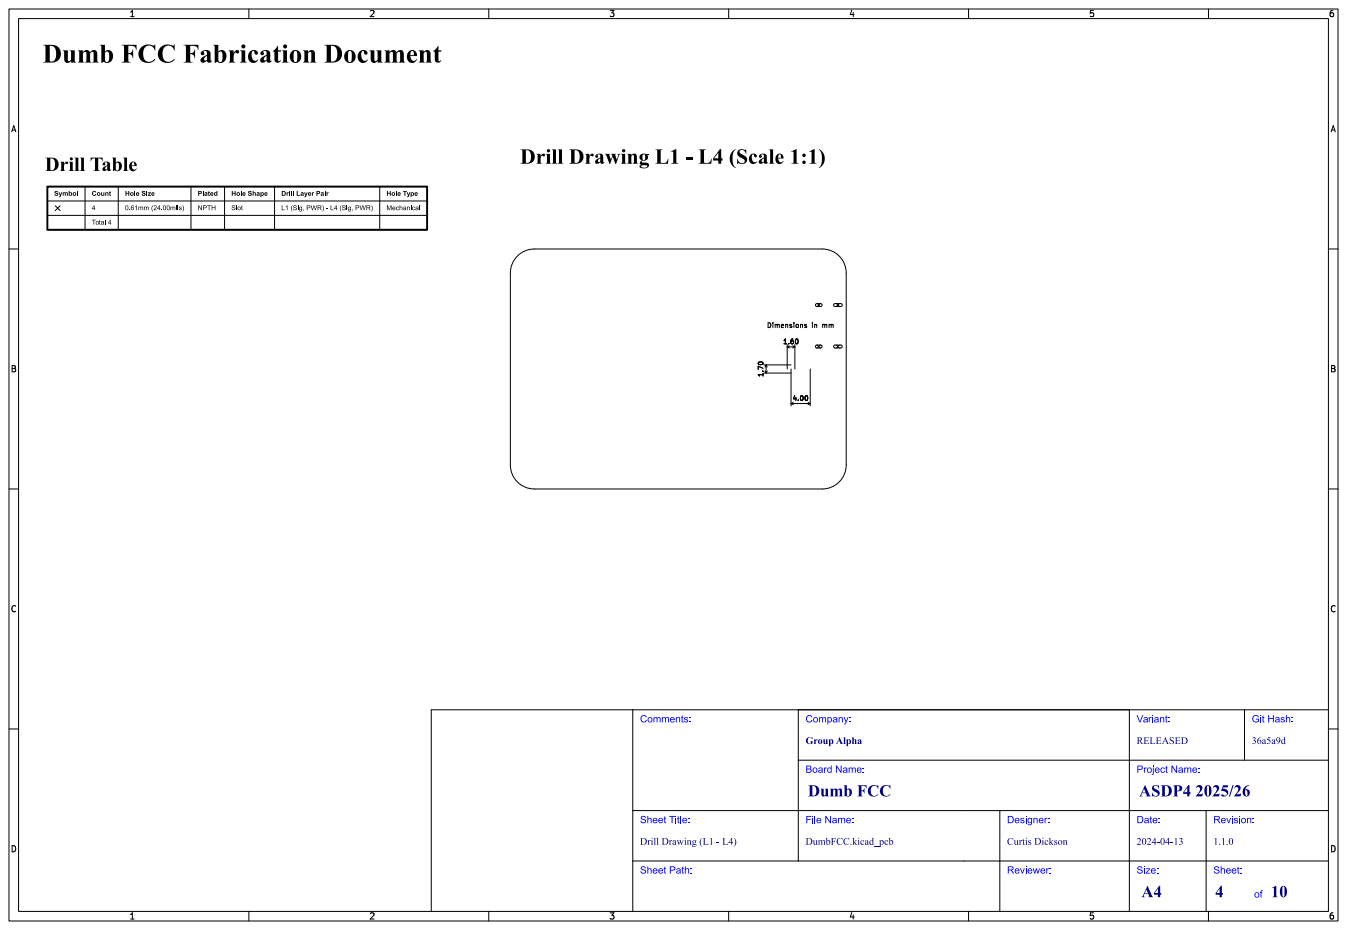
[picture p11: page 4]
Git; Hash:; Comments:; Drill Drawing (L1 - L4); Sheet Path:; Sheet Title:; File Name:; Dumb FCC; ASDP4 2025/26; Group Alpha; Company:; RELEASED; Variant:; Board Name:; DumbFCC.kicad_pcb; Curtis Dickson; Designer:; Reviewer:; Project Name:; Date:; Revision:; Size:; Sheet:

Dimensions in mm

# Top Test Points (Scale 1:1)

# Dumb FCC Fabrication Document

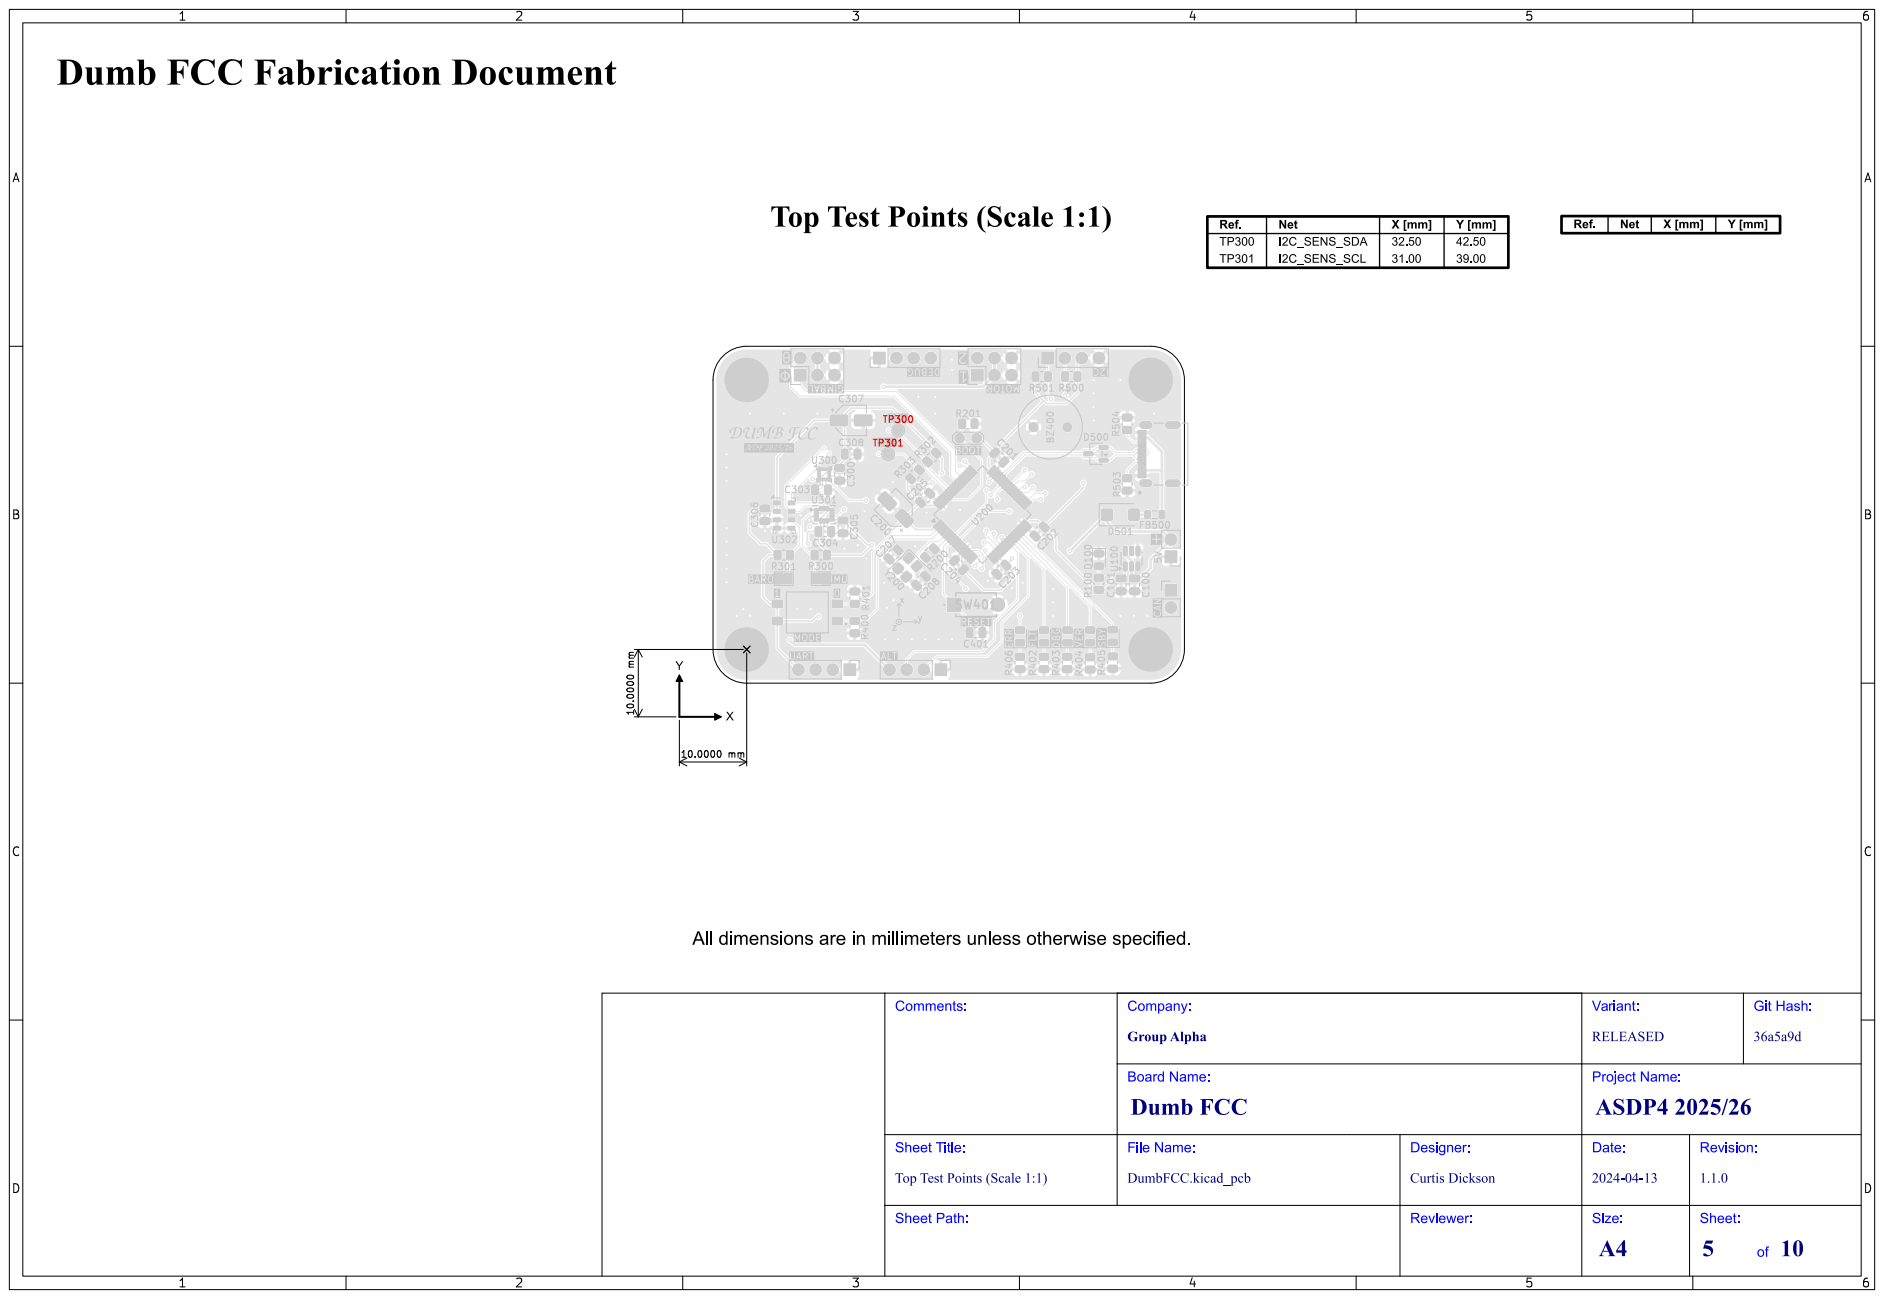
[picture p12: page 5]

Top Test Points (Scale 1:1)

# Bottom Test Points (Scale 1:1)

# Dumb FCC Fabrication Document

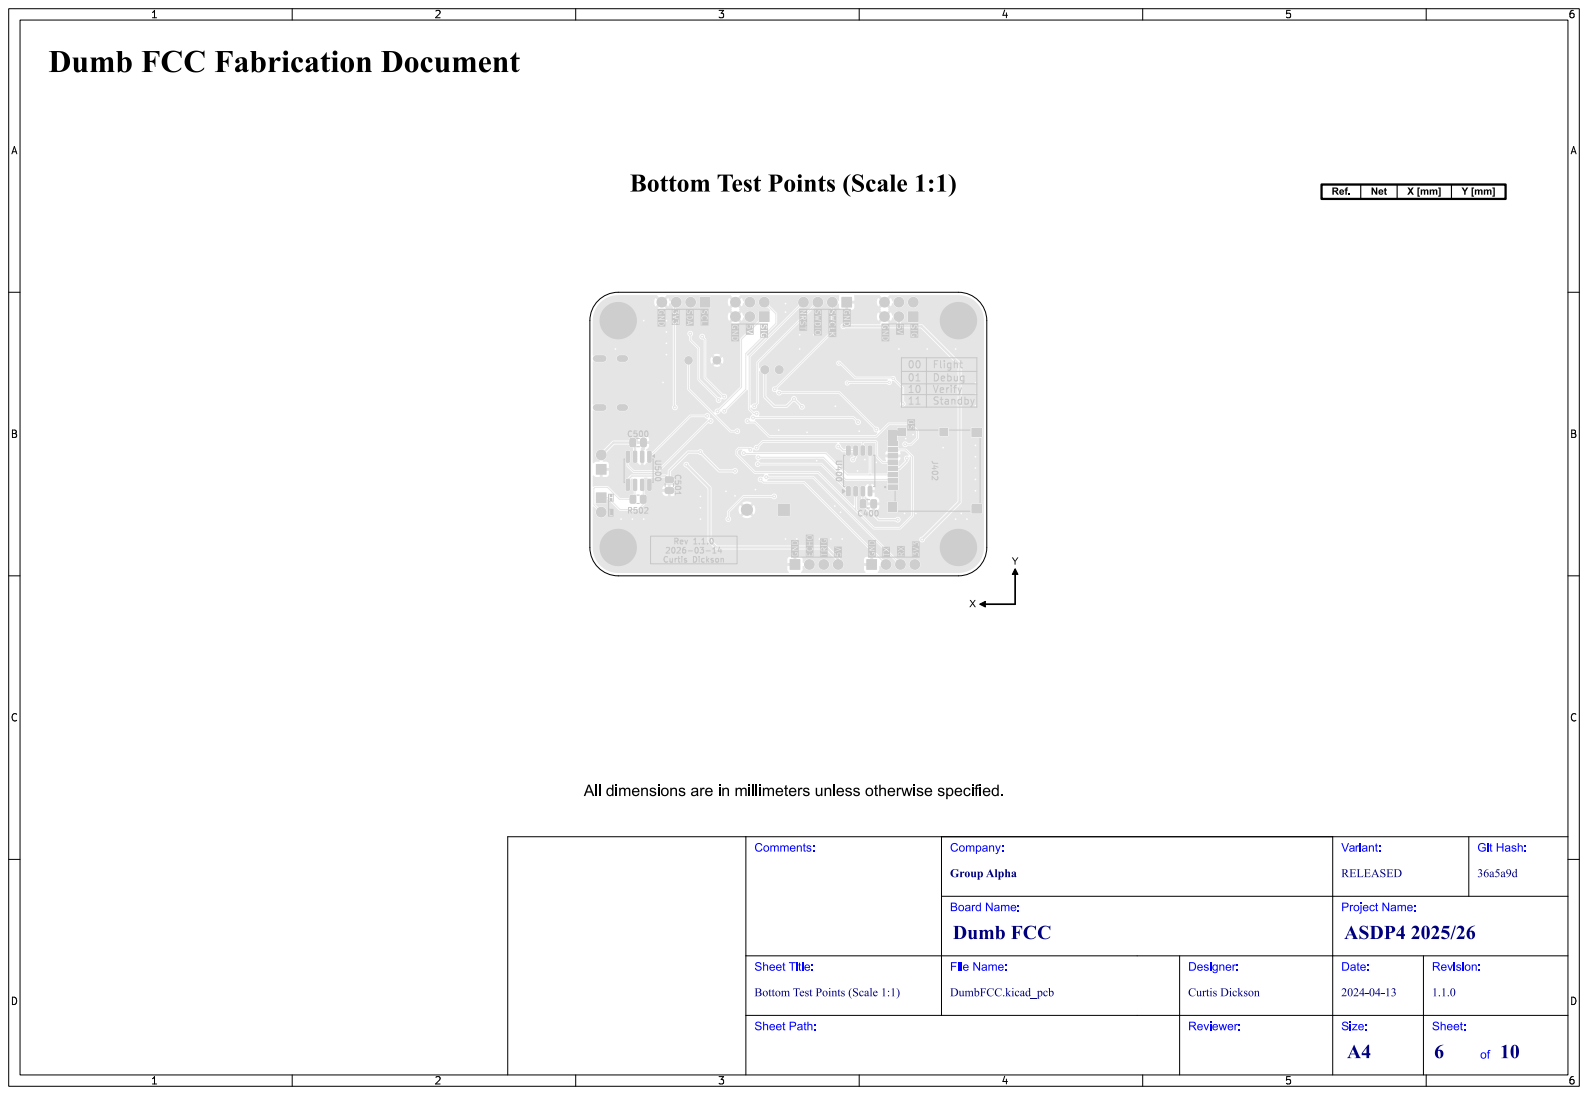
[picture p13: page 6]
Git; Hash:; Comments:; Sheet Path:; Sheet Title:; File Name:; Dumb FCC; ASDP4 2025/26; Group Alpha; Company:; RELEASED; Variant:; Board Name:; DumbFCC.kicad_pcb; Curtis Dickson; Designer:; Reviewer:; Project Name:; Date:; Revision:; Size:; Sheet:; Rev 1.1.0

00 | Flight
01 | Debug
10 | Verify
11 | Standby

Bottom Test Points (Scale 1:1)

# L1 (Sig, PWR) (Scale 1:1)

# Dumb FCC Fabrication Document

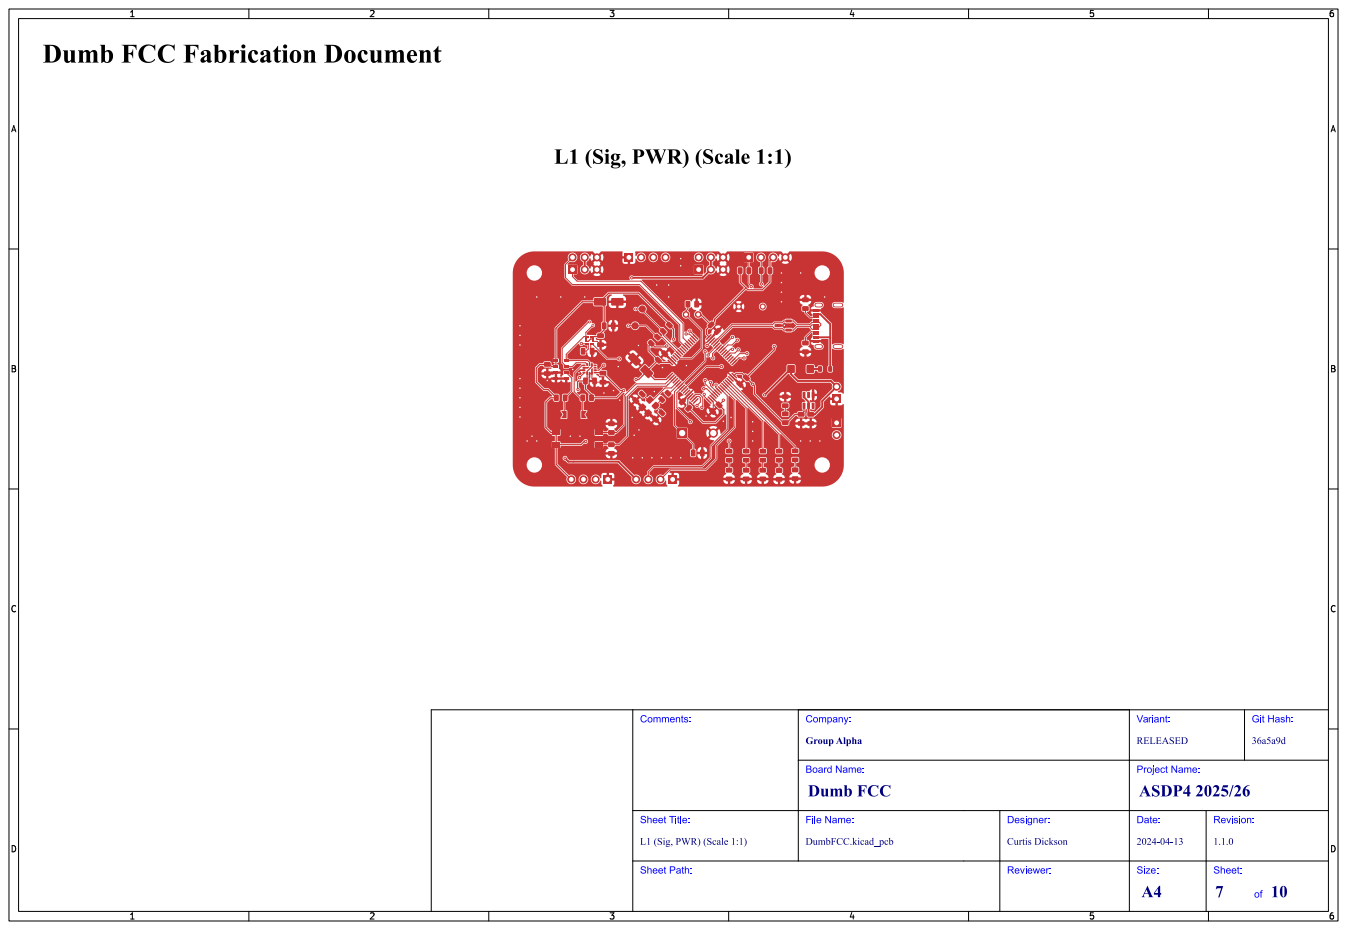
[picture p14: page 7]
Git; Hash:; Comments:; Sheet Path:; Sheet Title:; File Name:; Dumb FCC; ASDP4 2025/26; Group Alpha; Company:; RELEASED; Variant:; Board Name:; DumbFCC.kicad_pcb; Curtis Dickson; Designer:; Reviewer:; Project Name:; Date:; Revision:; Size:; Sheet:

L1 (Sig, PWR) (Scale 1:1)

# L2 (GND) (Scale 1:1)

# Dumb FCC Fabrication Document

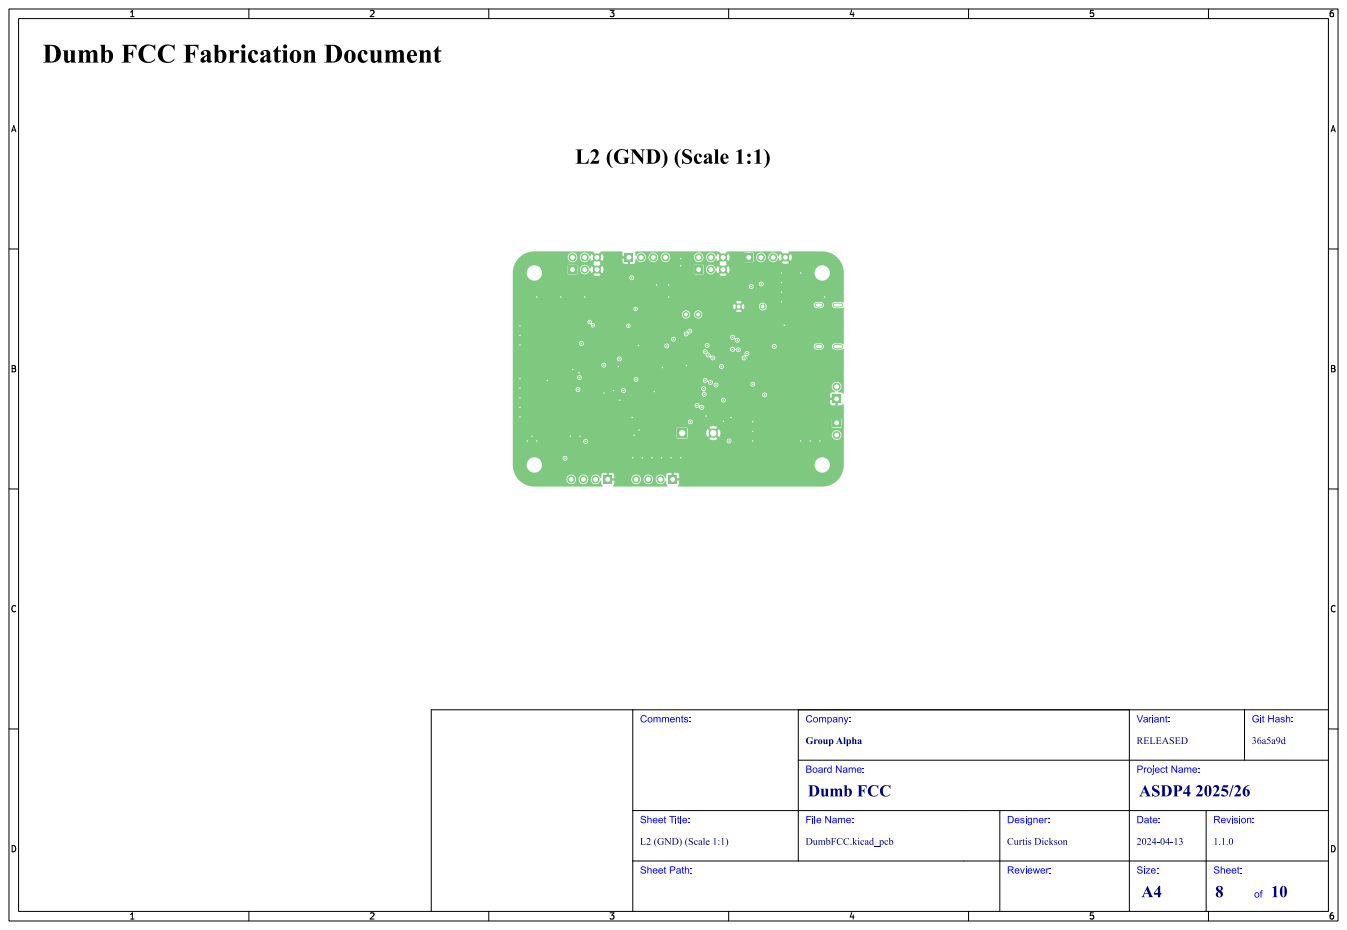
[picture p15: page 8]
Git; Hash:; Comments:; L2 (GND) (Scale 1:1); Sheet Path:; Sheet Title:; File Name:; Dumb FCC; ASDP4 2025/26; Group Alpha; Company:; RELEASED; Variant:; Board Name:; DumbFCC.kicad_pcb; Curtis Dickson; Designer:; Reviewer:; Project Name:; Date:; Revision:; Size:; Sheet:

# L3 (GND) (Scale 1:1)

# Dumb FCC Fabrication Document

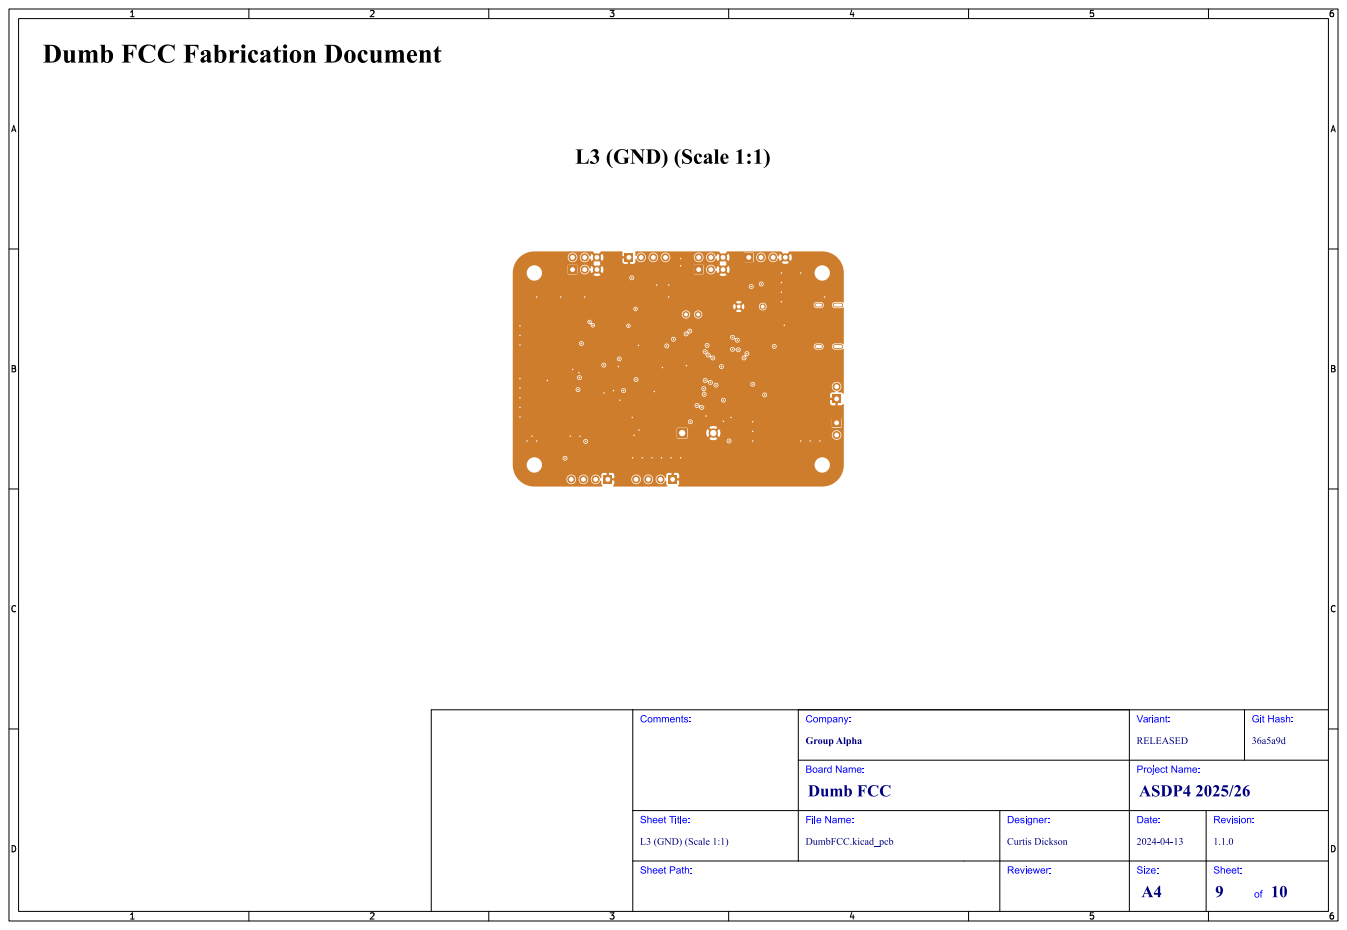
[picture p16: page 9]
Git; Hash:; Comments:; L3 (GND) (Scale 1:1); Sheet Path:; Sheet Title:; File Name:; Dumb FCC; ASDP4 2025/26; Group Alpha; Company:; RELEASED; Variant:; Board Name:; DumbFCC.kicad_pcb; Curtis Dickson; Designer:; Reviewer:; Project Name:; Date:; Revision:; Size:; Sheet:

# L4 (Sig, PWR) (Scale 1:1)

# Dumb FCC Fabrication Document

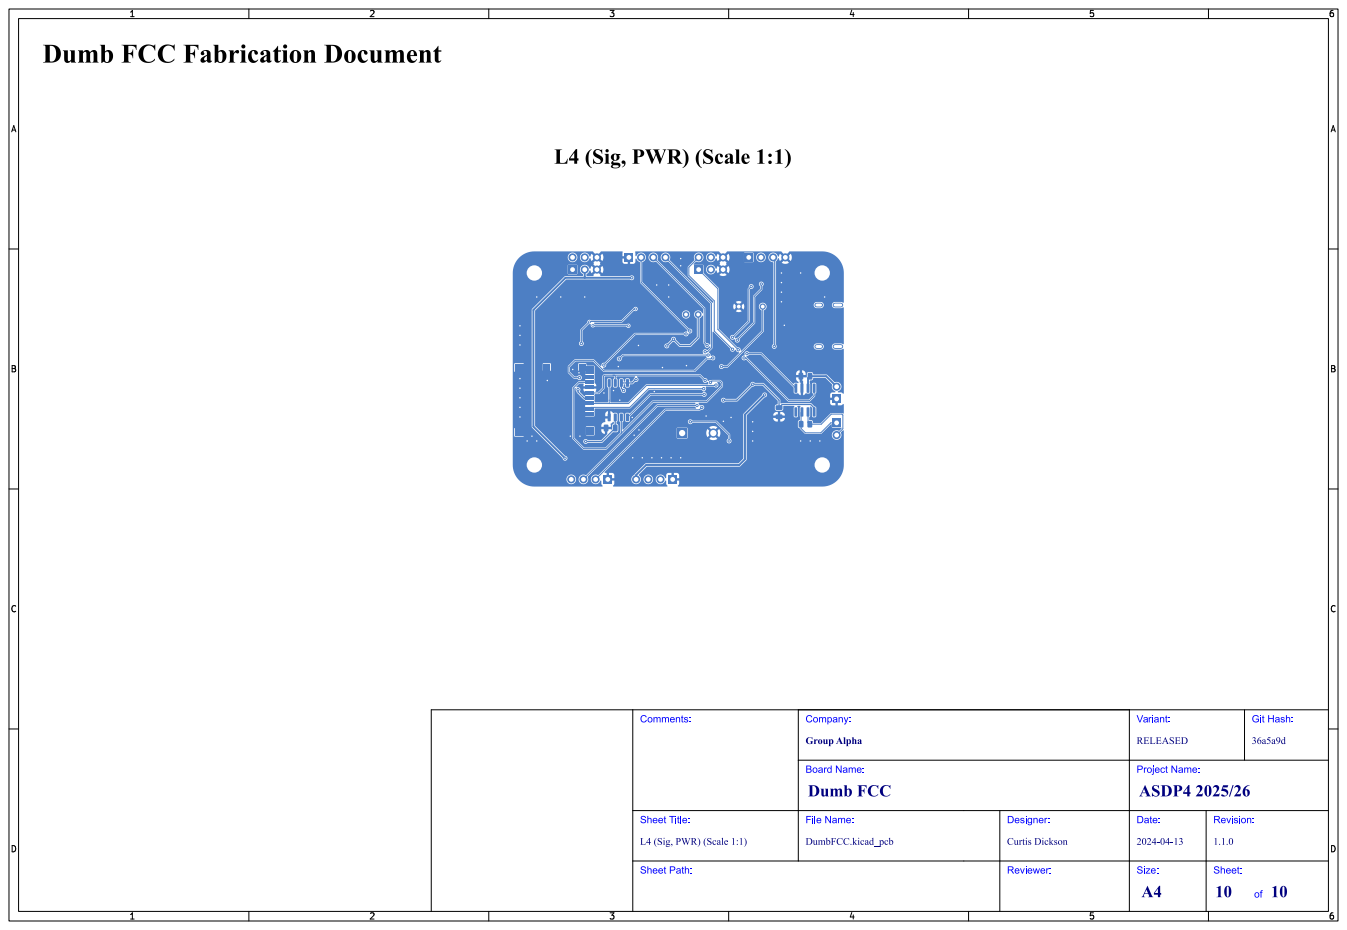
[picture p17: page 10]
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

L4 (Sig, PWR) (Scale 1:1)

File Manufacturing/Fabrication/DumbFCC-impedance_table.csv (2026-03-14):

Transmission Line | Impedance [ohms] | Tolerance [ohms] | Layer | Trace Width [mm] | Gap [mm] | Ref. Layers
USB Differential Pair | 90 | +/- 10% | L1 | 0.1547 | 0.2 | L2

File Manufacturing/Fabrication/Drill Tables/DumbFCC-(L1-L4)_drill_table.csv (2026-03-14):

Count | Hole Size | Plated | Hole Shape | Drill Layer Pair | Hole Type
101 | 0.30mm (11.81mils) | PTH | Round | L1 (Sig, PWR) - L4 (Sig, PWR) | Via
4 | 0.80mm (31.50mils) | PTH | Round | L1 (Sig, PWR) - L4 (Sig, PWR) | Pad
32 | 1.00mm (39.37mils) | PTH | Round | L1 (Sig, PWR) - L4 (Sig, PWR) | Pad
2 | 1.30mm (51.18mils) | PTH | Round | L1 (Sig, PWR) - L4 (Sig, PWR) | Pad
4 | 3.20mm (125.98mils) | PTH | Round | L1 (Sig, PWR) - L4 (Sig, PWR) | Pad
Total 143

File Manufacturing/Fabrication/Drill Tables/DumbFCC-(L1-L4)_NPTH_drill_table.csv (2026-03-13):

Count | Hole Size | Plated | Hole Shape | Drill Layer Pair | Hole Type
4 | 0.61mm (24.00mils) | NPTH | Slot | L1 (Sig, PWR) - L4 (Sig, PWR) | Mechanical
Total 4

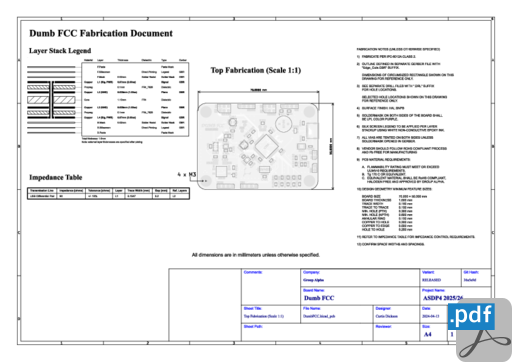
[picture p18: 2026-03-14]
HTML/images/cat_pdf_fabrication_DumbFCC-fabrication.png

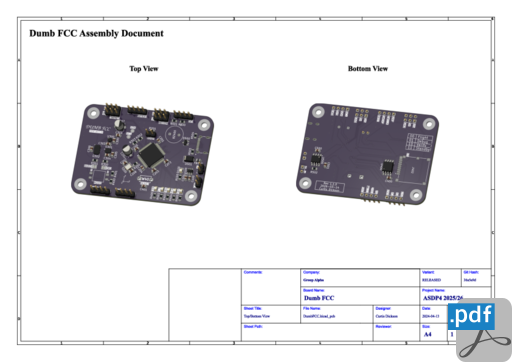
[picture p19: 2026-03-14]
HTML/images/cat_pdf_assembly_DumbFCC-assembly.png

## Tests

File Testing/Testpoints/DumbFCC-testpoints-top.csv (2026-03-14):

Ref. | Net | X [mm] | Y [mm]
TP300 | I2C_SENS_SDA | 32.50 | 42.50
TP301 | I2C_SENS_SCL | 31.00 | 39.00

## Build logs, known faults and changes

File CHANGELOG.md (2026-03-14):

# Changelog

## [Unreleased]

## [1.1.0] - 2026-03-14

### Fixed

-   Changed footprint of U302 to correct one
-   Changed footprint of D401 from 0805 to D0-214AC to match part availability 
-   Swapped the two TVS diodes to a combined package (ESDA6V1l-tp) with footprint SOT-23

### Changed

-   Changed the AT25DF321A-SH-T to the SST26VF064BT-104I/SM due to availability issues
-   Rerouted board 

## [1.0.0] - 2026-03-13

### Added

-   First version of schematic and PCB layout

[Unreleased]: https://github.com/Curtis-05/DumbFCC/compare/1.1.0...HEAD

[1.1.0]: https://github.com/Curtis-05/DumbFCC/compare/1.0.0...1.1.0

[1.0.0]: https://github.com/Curtis-05/DumbFCC/compare/e08e27189a18e6c835f4b7ac3e6732f94663e6cd...1.0.0

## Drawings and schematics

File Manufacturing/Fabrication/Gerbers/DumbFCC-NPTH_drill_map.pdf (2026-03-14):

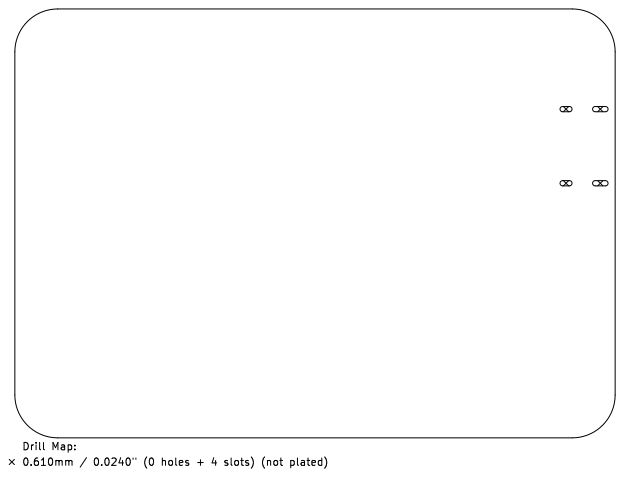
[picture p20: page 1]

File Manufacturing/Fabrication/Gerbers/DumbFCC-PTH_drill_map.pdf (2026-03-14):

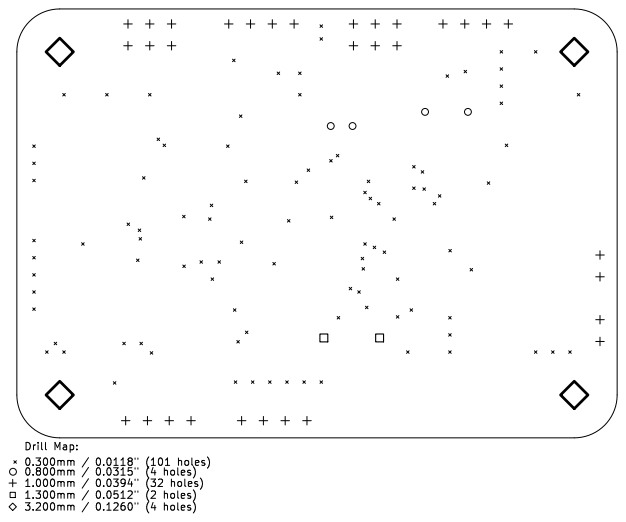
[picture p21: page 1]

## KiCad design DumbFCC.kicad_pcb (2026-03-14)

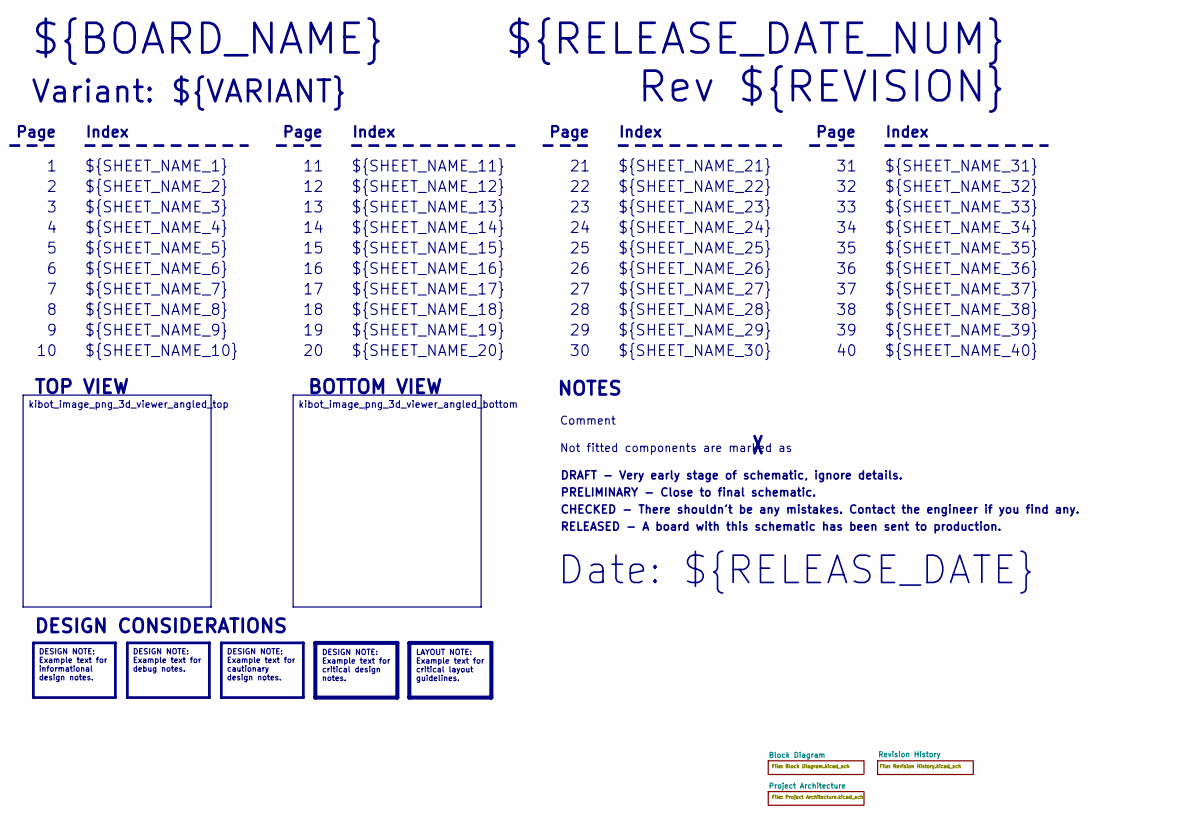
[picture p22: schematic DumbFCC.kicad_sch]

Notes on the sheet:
Variant: ${VARIANT}
RELEASED - A board with this schematic has been sent to production.
${SHEET_NAME_24}
Index
Page
PRELIMINARY - Close to final schematic.
${SHEET_NAME_22}
DRAFT - Very early stage of schematic, ignore details.
${SHEET_NAME_12}
${SHEET_NAME_8}
${SHEET_NAME_2}
${SHEET_NAME_5}
${SHEET_NAME_20}
${SHEET_NAME_23}
${RELEASE_DATE_NUM}
${SHEET_NAME_35}
Not fitted components are marked as
${SHEET_NAME_11}
${SHEET_NAME_6}
${SHEET_NAME_37}
${SHEET_NAME_26}
${SHEET_NAME_36}
Rev ${REVISION}
${SHEET_NAME_15}
CHECKED - There shouldn't be any mistakes. Contact the engineer if you find any.
BOTTOM VIEW
${SHEET_NAME_14}
${SHEET_NAME_21}
${SHEET_NAME_17}
${SHEET_NAME_18}
Date: ${RELEASE_DATE}
${SHEET_NAME_7}
${SHEET_NAME_31}
${BOARD_NAME}
NOTES
${SHEET_NAME_40}
${SHEET_NAME_39}
${SHEET_NAME_32}
${SHEET_NAME_1}
${SHEET_NAME_9}


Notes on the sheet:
${RELEASE_BODY_1.1.0}
[${#}] ${TITLE}
${RELEASE_BODY_1.0.0}
${RELEASE_TITLE_1.0.2}
${RELEASE_BODY_1.0.2}
${RELEASE_BODY_1.0.1}
${RELEASE_TITLE_1.0.0}
${RELEASE_TITLE_1.0.1}
${RELEASE_TITLE_1.1.0}

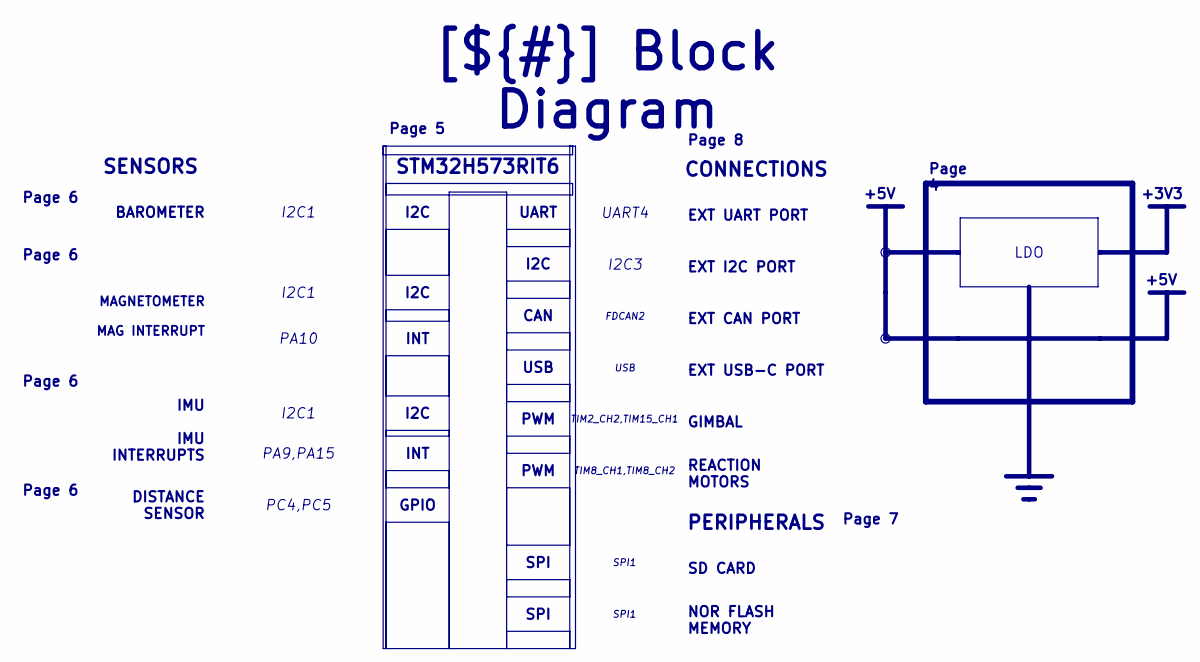
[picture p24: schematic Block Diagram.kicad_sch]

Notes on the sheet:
+5V
+3V3
Page 6
SD CARD
Page 5
I2C3
I2C
UART4
SPI1
I2C1
LDO
UART
Page 8
SPI
CAN
PC4,PC5
IMU IMU INTERRUPTS
GPIO
Page 4
TIM2_CH2,TIM15_CH1
EXT CAN PORT
NOR FLASH MEMORY
PA9,PA15
Page 7
PA10
[${#}] ${TITLE}
INT
PERIPHERALS
GIMBAL
FDCAN2
EXT I2C PORT
MAGNETOMETER MAG INTERRUPT
PWM
USB
SENSORS
TIM8_CH1,TIM8_CH2
DISTANCE SENSOR
CONNECTIONS
EXT UART PORT
STM32H573RIT6

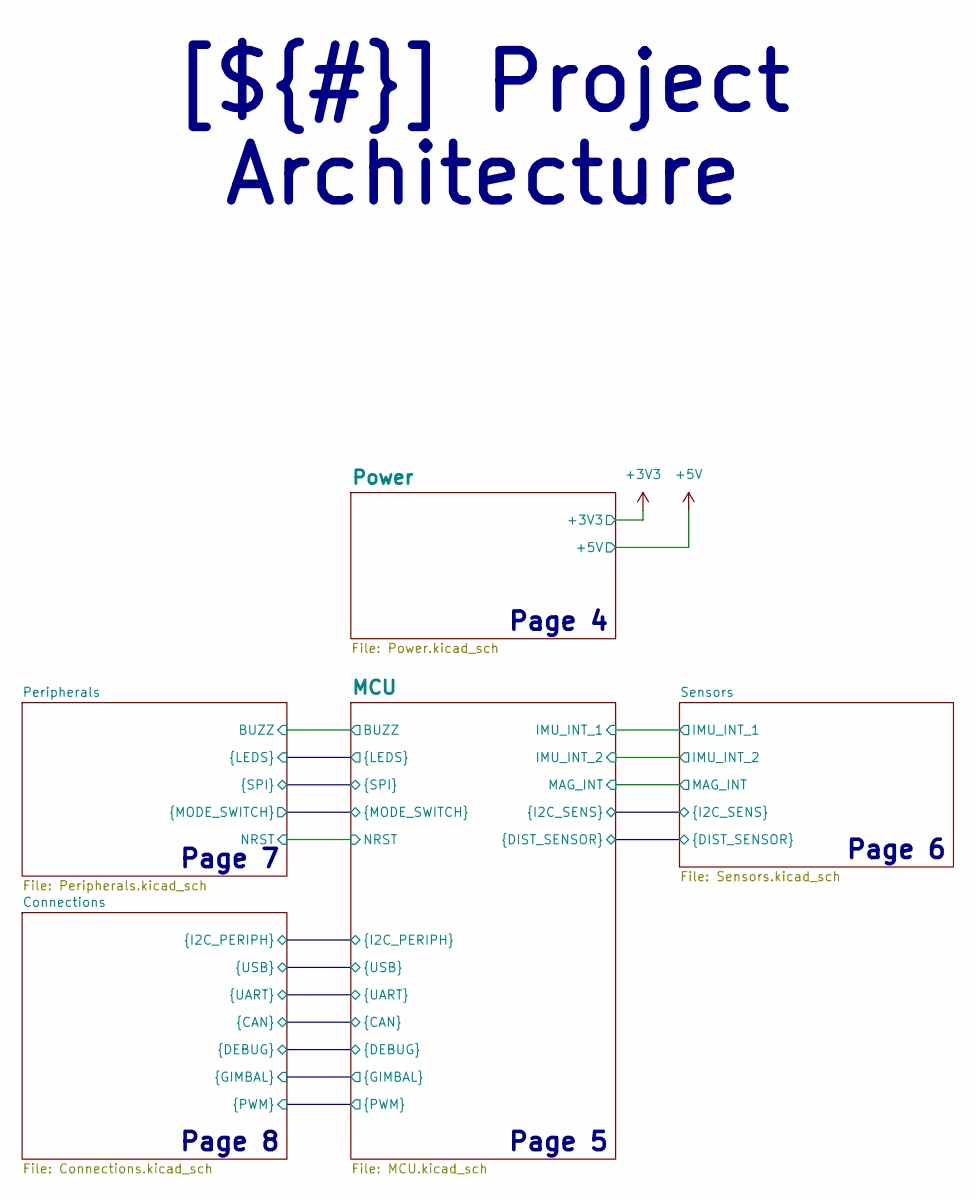
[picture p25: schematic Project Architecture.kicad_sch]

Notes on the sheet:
Page 7
Page 8
Page 5
Page 4
Page 6
[${#}] ${TITLE}

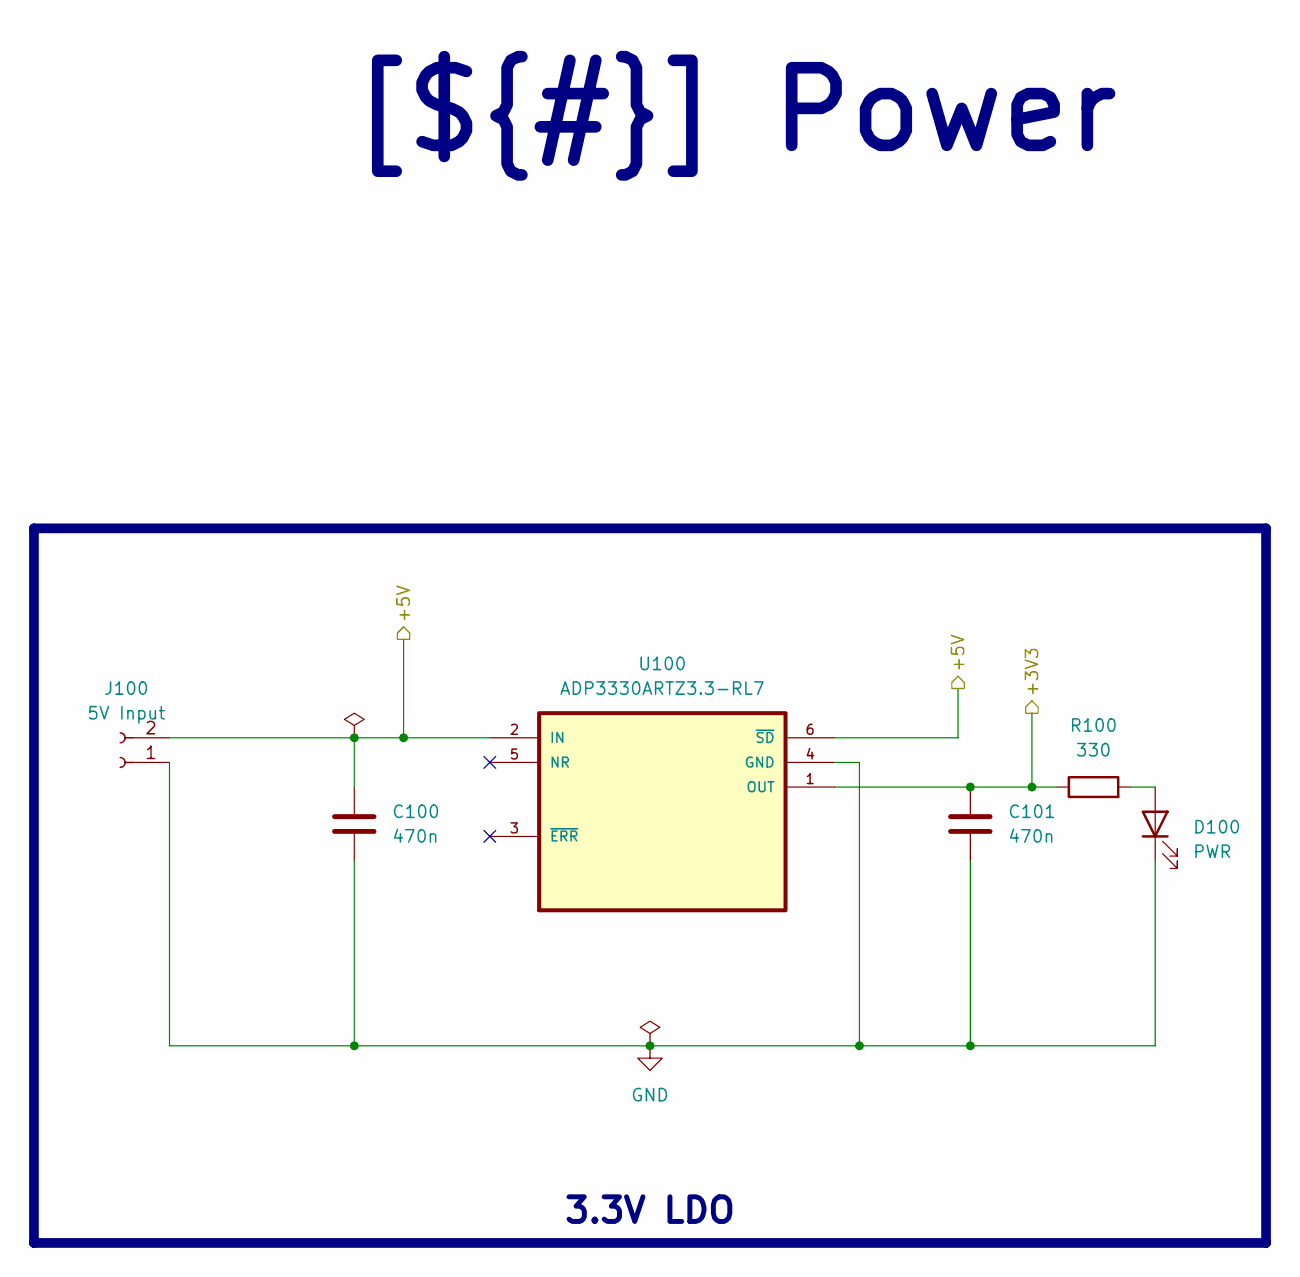
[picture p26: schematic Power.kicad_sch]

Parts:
C100, C101: 470n; C_0805_2012Metric
D100: PWR; LED_0805_2012Metric
J100: 5V Input; PinHeader_1x02_P2.54mm_Vertical
R100: 330; R_0805_2012Metric
U100: ADP3330ARTZ3.3-RL7; SOT-23-6

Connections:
+3V3: C101.1, R100.1, U100.1 (OUT); also elsewhere on the board
+5V: C100.1, J100.2, U100.2 (IN), U100.6 (~SD); also elsewhere on the board
GND: C100.2, C101.2, D100.1 (K), J100.1, U100.4 (GND); also elsewhere on the board
unnamed: D100.2 (A), R100.2

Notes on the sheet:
[${#}] ${TITLE}
3.3V LDO

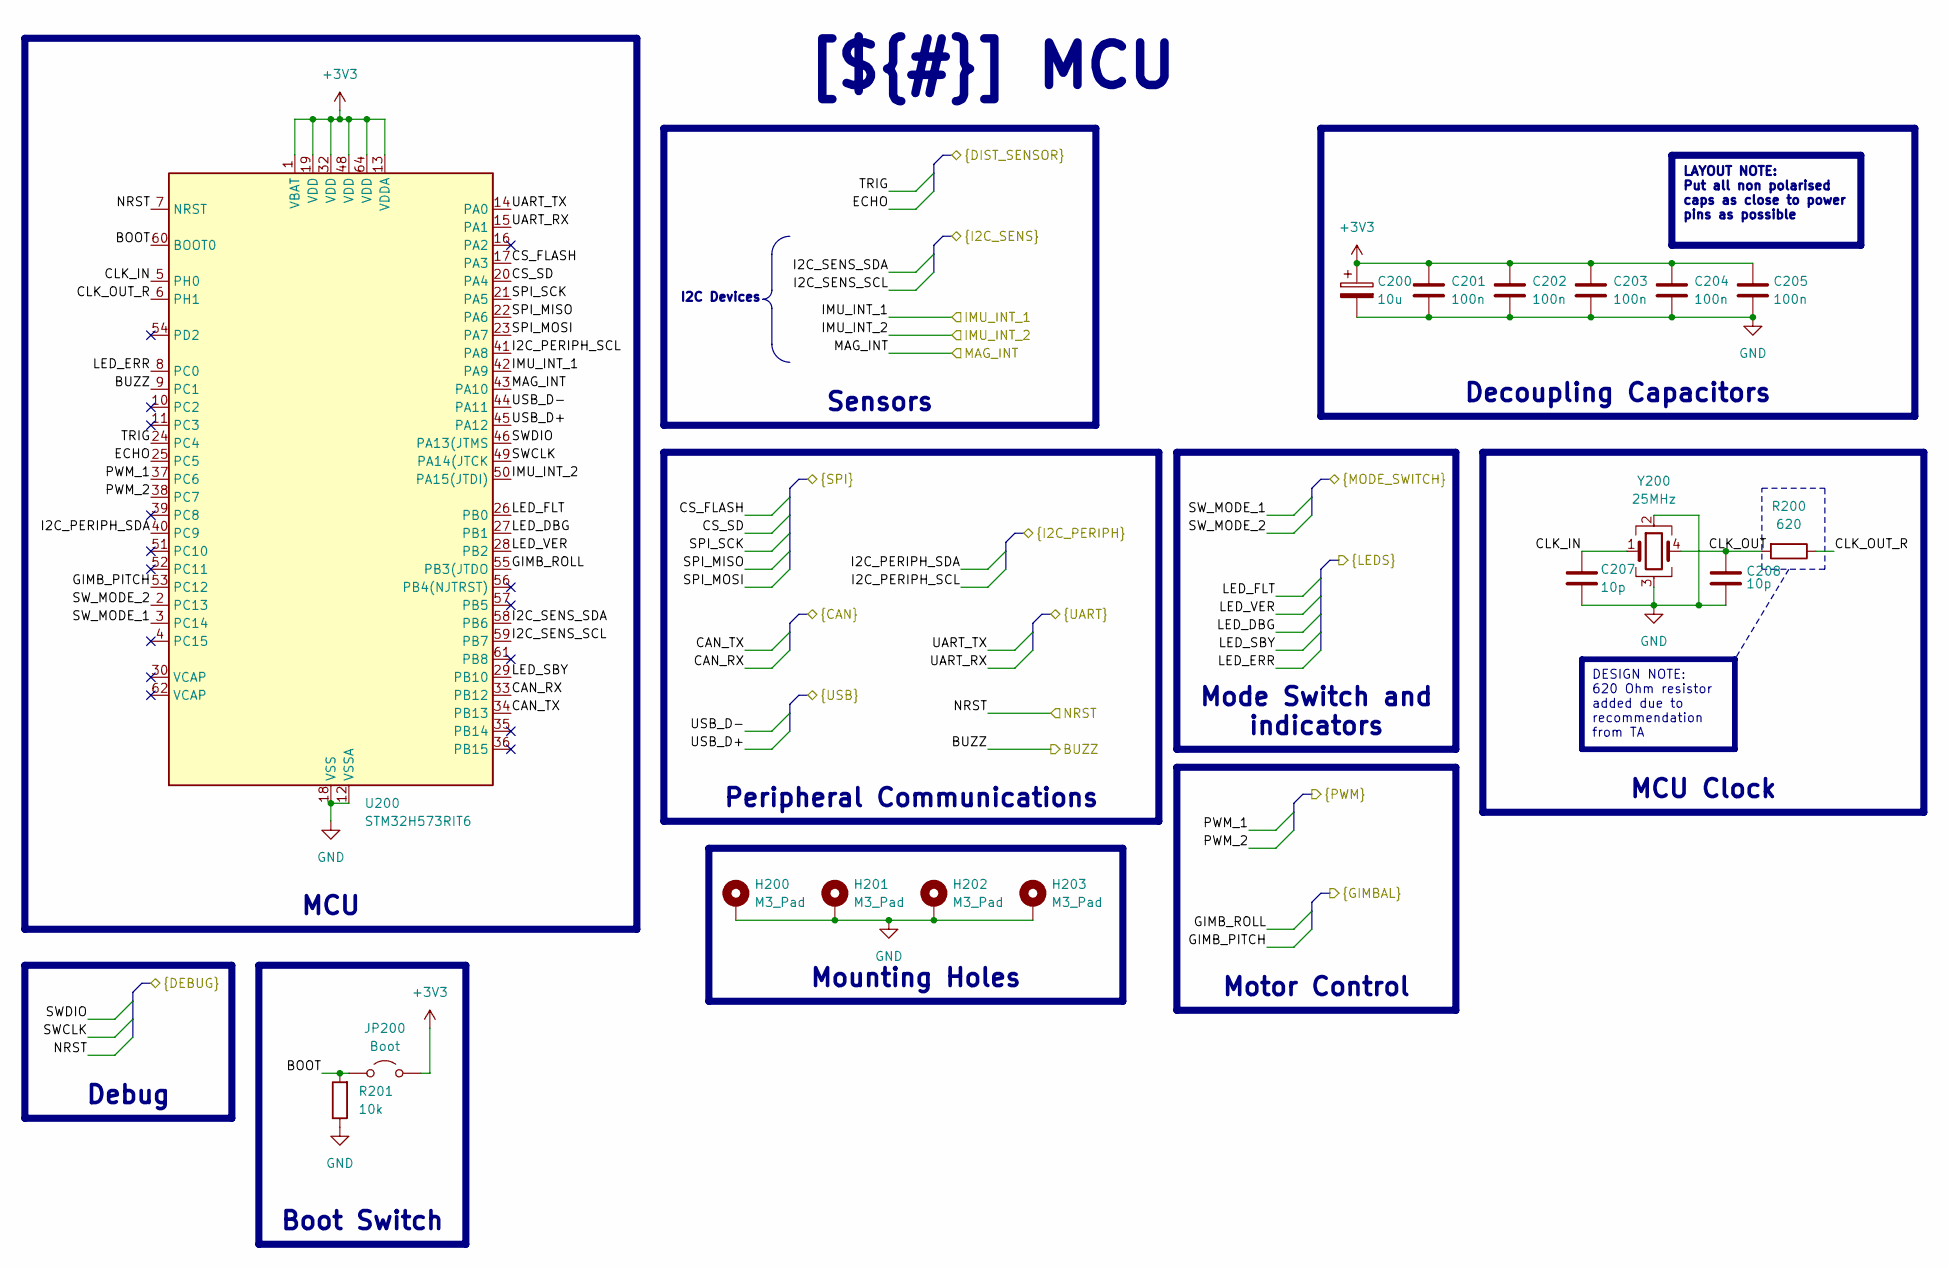
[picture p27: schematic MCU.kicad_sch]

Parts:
C200: 10u; CP_Elec_4x5.7
C201, C202, C203, C204, C205: 100n; C_0805_2012Metric
C207, C208: 10p; C_0805_2012Metric
H200, H201, H202, H203: M3_Pad; MountingHole_3.2mm_M3_Pad_TopBottom
JP200: Boot; TestPoint_2Pads_Pitch2.54mm_Drill0.8mm
R200: 620; R_0805_2012Metric
R201: 10k; R_0805_2012Metric
U200: STM32H573RIT6; LQFP-64_10x10mm_P0.5mm
Y200: 25MHz; Crystal_SMD_Abracon_ABM8G-4Pin_3.2x2.5mm

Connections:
+3V3: C200.1, C201.1, C202.1, C203.1, C204.1, C205.1, JP200.2 (B), U200.1 (VBAT), U200.13 (VDDA), U200.19 (VDD), U200.32 (VDD), U200.48 (VDD), U200.64 (VDD); also elsewhere on the board
/Project Architecture/Connections/CAN_RX: U200.33 (PB12); also elsewhere on the board
/Project Architecture/Connections/CAN_TX: U200.34 (PB13); also elsewhere on the board
/Project Architecture/Connections/GIMB_PITCH: U200.53 (PC12); also elsewhere on the board
/Project Architecture/Connections/GIMB_ROLL: U200.55 (PB3(JTDO); also elsewhere on the board
/Project Architecture/Connections/I2C_PERIPH_SCL: U200.41 (PA8); also elsewhere on the board
/Project Architecture/Connections/I2C_PERIPH_SDA: U200.40 (PC9); also elsewhere on the board
/Project Architecture/Connections/NRST: U200.7 (NRST); also elsewhere on the board
/Project Architecture/Connections/PWM_1: U200.37 (PC6); also elsewhere on the board
/Project Architecture/Connections/PWM_2: U200.38 (PC7); also elsewhere on the board
/Project Architecture/Connections/SWCLK: U200.49 (PA14(JTCK); also elsewhere on the board
/Project Architecture/Connections/SWDIO: U200.46 (PA13(JTMS); also elsewhere on the board
/Project Architecture/Connections/UART_RX: U200.15 (PA1); also elsewhere on the board
/Project Architecture/Connections/UART_TX: U200.14 (PA0); also elsewhere on the board
/Project Architecture/Connections/USB_D+: U200.45 (PA12); also elsewhere on the board
/Project Architecture/Connections/USB_D-: U200.44 (PA11); also elsewhere on the board
/Project Architecture/MCU/BOOT: JP200.1 (A), R201.2, U200.60 (BOOT0)
/Project Architecture/MCU/BUZZ: U200.9 (PC1); also elsewhere on the board
/Project Architecture/MCU/CLK_IN: C207.1, U200.5 (PH0), Y200.1
/Project Architecture/MCU/CLK_OUT: C208.1, R200.2, Y200.4
/Project Architecture/MCU/CLK_OUT_R: R200.1, U200.6 (PH1)
/Project Architecture/MCU/CS_FLASH: U200.17 (PA3); also elsewhere on the board
/Project Architecture/MCU/CS_SD: U200.20 (PA4); also elsewhere on the board
/Project Architecture/MCU/ECHO: U200.25 (PC5); also elsewhere on the board
/Project Architecture/MCU/I2C_SENS_SCL: U200.59 (PB7); also elsewhere on the board
/Project Architecture/MCU/I2C_SENS_SDA: U200.58 (PB6); also elsewhere on the board
/Project Architecture/MCU/IMU_INT_1: U200.42 (PA9); also elsewhere on the board
/Project Architecture/MCU/IMU_INT_2: U200.50 (PA15(JTDI)); also elsewhere on the board
/Project Architecture/MCU/LED_DBG: U200.27 (PB1); also elsewhere on the board
/Project Architecture/MCU/LED_ERR: U200.8 (PC0); also elsewhere on the board
/Project Architecture/MCU/LED_FLT: U200.26 (PB0); also elsewhere on the board
/Project Architecture/MCU/LED_SBY: U200.29 (PB10); also elsewhere on the board
/Project Architecture/MCU/LED_VER: U200.28 (PB2); also elsewhere on the board
/Project Architecture/MCU/MAG_INT: U200.43 (PA10); also elsewhere on the board
/Project Architecture/MCU/SPI_MISO: U200.22 (PA6); also elsewhere on the board
/Project Architecture/MCU/SPI_MOSI: U200.23 (PA7); also elsewhere on the board
/Project Architecture/MCU/SPI_SCK: U200.21 (PA5); also elsewhere on the board
/Project Architecture/MCU/SW_MODE_1: U200.3 (PC14); also elsewhere on the board
/Project Architecture/MCU/SW_MODE_2: U200.2 (PC13); also elsewhere on the board
/Project Architecture/MCU/TRIG: U200.24 (PC4); also elsewhere on the board
GND: C200.2, C201.2, C202.2, C203.2, C204.2, C205.2, C207.2, C208.2, H200.1, H201.1, H202.1, H203.1, R201.1, U200.12 (VSSA), U200.18 (VSS), U200.31 (VSS), U200.47 (VSS), U200.63 (VSS), Y200.2, Y200.3; also elsewhere on the board

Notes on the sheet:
DESIGN NOTE: 620 Ohm resistor added due to recommendation from TA
Sensors
Debug
Mode Switch and indicators
Peripheral Communications
Mounting Holes
LAYOUT NOTE: Put all non polarised caps as close to power pins as possible
[${#}] ${TITLE}
Boot Switch
I2C Devices
Motor Control
MCU Clock
MCU
Decoupling Capacitors

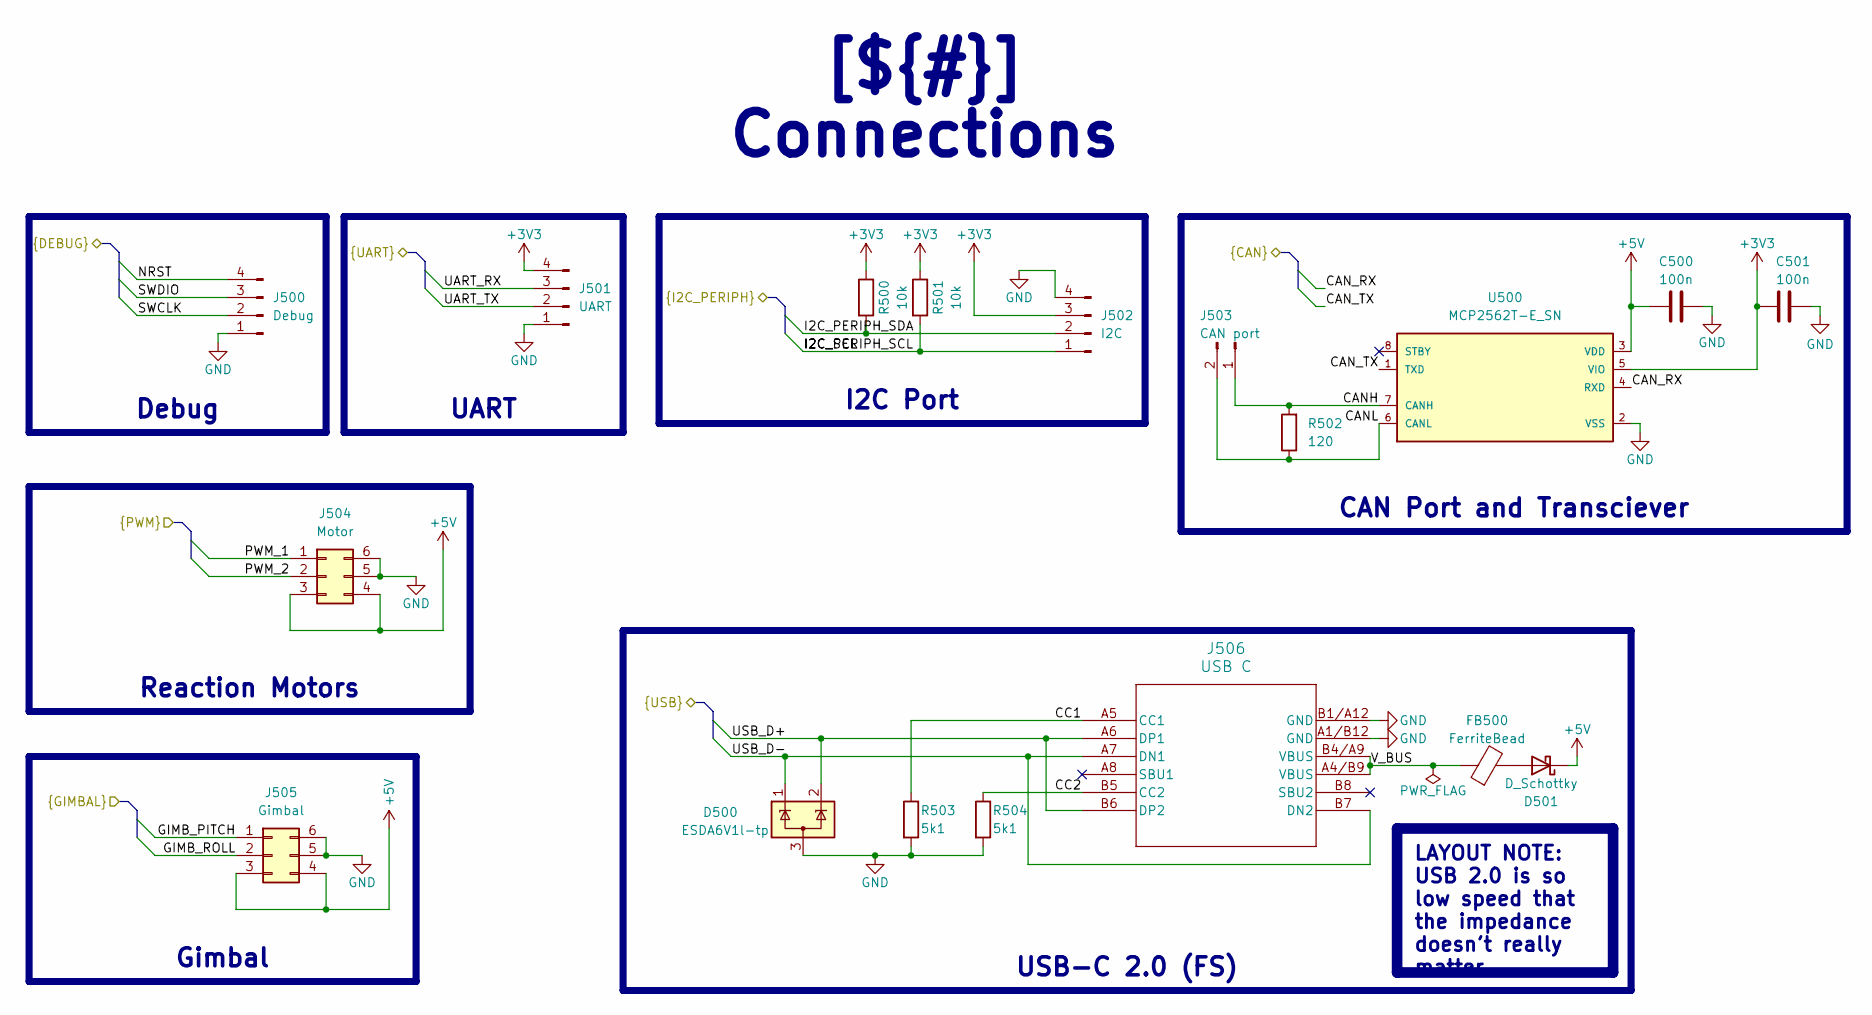
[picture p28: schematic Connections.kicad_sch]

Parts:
C500, C501: 100n; C_0805_2012Metric
D500: ESDA6V1l-tp; SOT-23-3
D501: D_Schottky; P25_DO-214AC_SMA
FB500: FerriteBead; L_0805_2012Metric
J500: Debug; PinHeader_1x04_P2.54mm_Vertical
J501: UART; PinHeader_1x04_P2.54mm_Vertical
J502: I2C; PinHeader_1x04_P2.54mm_Vertical
J503: CAN port; PinHeader_1x02_P2.54mm_Vertical
J504: Motor; PinHeader_2x03_P2.54mm_Vertical
J505: Gimbal; PinHeader_2x03_P2.54mm_Vertical
J506: USB C; 2171790001_MOL
R500, R501: 10k; R_0805_2012Metric
R502: 120; R_0805_2012Metric
R503, R504: 5k1; R_0805_2012Metric
U500: MCP2562T-E_SN; SOIC-8_3.9x4.9mm_P1.27mm

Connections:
+3V3: C501.2, J501.4, J502.3, R500.1, R501.1, U500.5 (VIO); also elsewhere on the board
+5V: C500.2, D501.1 (K), J504.3, J504.4, J505.3, J505.4, U500.3 (VDD); also elsewhere on the board
/Project Architecture/Connections/CANH: J503.1, R502.2, U500.7 (CANH)
/Project Architecture/Connections/CANL: J503.2, R502.1, U500.6 (CANL)
/Project Architecture/Connections/CAN_RX: U500.4 (RXD); also elsewhere on the board
/Project Architecture/Connections/CAN_TX: U500.1 (TXD); also elsewhere on the board
/Project Architecture/Connections/CC1: J506.A5 (CC1), R503.1
/Project Architecture/Connections/CC2: J506.B5 (CC2), R504.1
/Project Architecture/Connections/GIMB_PITCH: J505.1; also elsewhere on the board
/Project Architecture/Connections/GIMB_ROLL: J505.2; also elsewhere on the board
/Project Architecture/Connections/I2C_PERIPH_SCL: J502.1, R501.2; also elsewhere on the board
/Project Architecture/Connections/I2C_PERIPH_SDA: J502.2, R500.2; also elsewhere on the board
/Project Architecture/Connections/NRST: J500.4; also elsewhere on the board
/Project Architecture/Connections/PWM_1: J504.1; also elsewhere on the board
/Project Architecture/Connections/PWM_2: J504.2; also elsewhere on the board
/Project Architecture/Connections/SWCLK: J500.2; also elsewhere on the board
/Project Architecture/Connections/SWDIO: J500.3; also elsewhere on the board
/Project Architecture/Connections/UART_RX: J501.3; also elsewhere on the board
/Project Architecture/Connections/UART_TX: J501.2; also elsewhere on the board
/Project Architecture/Connections/USB_D+: D500.2 (K), J506.A6 (DP1), J506.B6 (DP2); also elsewhere on the board
/Project Architecture/Connections/USB_D-: D500.1 (K), J506.A7 (DN1), J506.B7 (DN2); also elsewhere on the board
/Project Architecture/Connections/V_BUS: FB500.1, J506.A4/B9 (VBUS), J506.B4/A9 (VBUS)
GND: C500.1, C501.1, D500.3 (A), J500.1, J501.1, J502.4, J504.5, J504.6, J505.5, J505.6, J506.A1/B12 (GND), J506.B1/A12 (GND), R503.2, R504.2, U500.2 (VSS); also elsewhere on the board
unnamed: D501.2 (A), FB500.2

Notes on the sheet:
USB-C 2.0 (FS)
Reaction Motors
I2C Port
Debug
Gimbal
[${#}] ${TITLE}
LAYOUT NOTE: USB 2.0 is so low speed that the impedance doesn't really matter
CAN Port and Transciever
UART

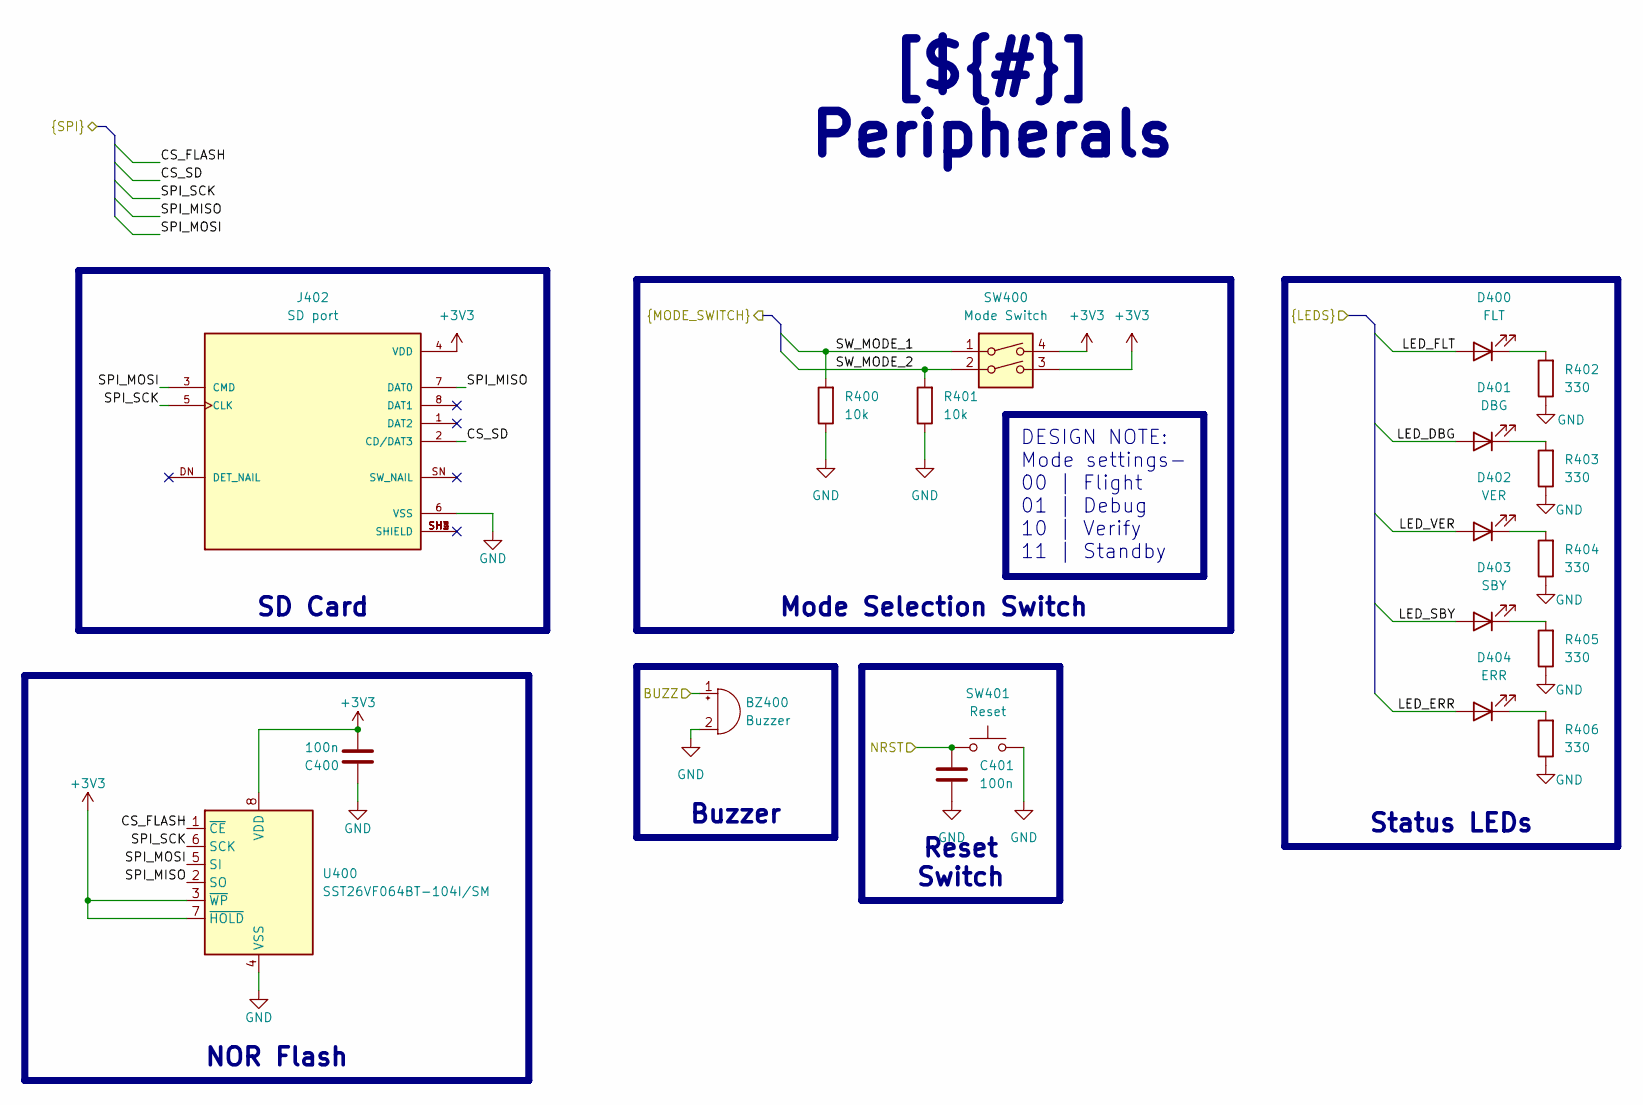
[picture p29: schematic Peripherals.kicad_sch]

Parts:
BZ400: Buzzer; XDCR_AI-1027-TWT-3V-R
C400, C401: 100n; C_0805_2012Metric
D400: FLT; LED_0805_2012Metric
D401: DBG; LED_0805_2012Metric
D402: VER; LED_0805_2012Metric
D403: SBY; LED_0805_2012Metric
D404: ERR; LED_0805_2012Metric
J402: SD port; MOLEX_5027740891
R400, R401: 10k; R_0805_2012Metric
R402, R403, R404, R405, R406: 330; R_0805_2012Metric
SW400: Mode Switch; SW_DS04-254-1-02BK-SMT
SW401: Reset; DTS32NVB
U400: SST26VF064BT-104I/SM; SOIC-8_5.3x5.3mm_P1.27mm

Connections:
+3V3: C400.1, J402.4 (VDD), SW400.3, SW400.4, U400.3 (~WP), U400.7 (~HOLD), U400.8 (VDD); also elsewhere on the board
/Project Architecture/Connections/NRST: C401.1, SW401.1; also elsewhere on the board
/Project Architecture/MCU/BUZZ: BZ400.1 (+); also elsewhere on the board
/Project Architecture/MCU/CS_FLASH: U400.1 (~CE); also elsewhere on the board
/Project Architecture/MCU/CS_SD: J402.2 (CD/DAT3); also elsewhere on the board
/Project Architecture/MCU/LED_DBG: D401.2 (A); also elsewhere on the board
/Project Architecture/MCU/LED_ERR: D404.2 (A); also elsewhere on the board
/Project Architecture/MCU/LED_FLT: D400.2 (A); also elsewhere on the board
/Project Architecture/MCU/LED_SBY: D403.2 (A); also elsewhere on the board
/Project Architecture/MCU/LED_VER: D402.2 (A); also elsewhere on the board
/Project Architecture/MCU/SPI_MISO: J402.7 (DAT0), U400.2 (SO); also elsewhere on the board
/Project Architecture/MCU/SPI_MOSI: J402.3 (CMD), U400.5 (SI); also elsewhere on the board
/Project Architecture/MCU/SPI_SCK: J402.5 (CLK), U400.6 (SCK); also elsewhere on the board
/Project Architecture/MCU/SW_MODE_1: R400.2, SW400.1; also elsewhere on the board
/Project Architecture/MCU/SW_MODE_2: R401.2, SW400.2; also elsewhere on the board
GND: BZ400.2 (-), C400.2, C401.2, J402.6 (VSS), R400.1, R401.1, R402.1, R403.1, R404.1, R405.1, R406.1, SW401.2, U400.4 (VSS); also elsewhere on the board
unnamed: D400.1 (K), R402.2
unnamed: D401.1 (K), R403.2
unnamed: D402.1 (K), R404.2
unnamed: D403.1 (K), R405.2
unnamed: D404.1 (K), R406.2

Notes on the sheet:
[${#}] ${TITLE}
Status LEDs
SD Card
Reset Switch
Mode Selection Switch
DESIGN NOTE: Mode settings- 00 | Flight 01 | Debug 10 | Verify 11 | Standby
NOR Flash
Buzzer

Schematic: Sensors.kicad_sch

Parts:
C300, C304, C305, C306, C308: 100n; C_0805_2012Metric
C303: 220n; C_0805_2012Metric
C307: 10u; CP_Elec_4x5.7
J300: Distance Sensor; PinHeader_1x04_P2.54mm_Vertical
JP300, JP302: SD0; SolderJumper-2_P1.3mm_Open_TrianglePad1.0x1.5mm
R300, R301, R302, R303: 10k; R_0805_2012Metric
TP300: SDA; TestPoint_Pad_D1.5mm
TP301: SCL; TestPoint_Pad_D1.5mm
U300: LIS2MDL; LGA-12_2x2mm_P0.5mm
U301: LSM6DSL; LGA-14_3x2.5mm_P0.5mm_LayoutBorder3x4y
U302: MS5607-02BA; LGA-8_3x5mm_P1.25mm

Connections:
+3V3: C300.2, C304.2, C305.1, C306.1, C307.1, C308.1, R300.1, R301.1, R302.1, R303.1, U300.3 (~CS), U300.9 (Vdd), U300.10 (Vdd_IO), U301.5 (VDDIO), U301.8 (VDD), U301.12 (CS), U302.1 (VDD), U302.2 (PS); also elsewhere on the board
+5V: J300.4; also elsewhere on the board
/Project Architecture/MCU/ECHO: J300.2; also elsewhere on the board
/Project Architecture/MCU/I2C_SENS_SCL: R303.2, TP301.1, U300.1 (SCL/SPC), U301.13 (SCL), U302.8 (SCLK); also elsewhere on the board
/Project Architecture/MCU/I2C_SENS_SDA: R302.2, TP300.1, U300.4 (SDA/SDI/SDO), U301.14 (SDA), U302.7 (SDI/SDA); also elsewhere on the board
/Project Architecture/MCU/IMU_INT_1: U301.4 (INT1); also elsewhere on the board
/Project Architecture/MCU/IMU_INT_2: U301.9 (INT2); also elsewhere on the board
/Project Architecture/MCU/MAG_INT: U300.7 (DRDY); also elsewhere on the board
/Project Architecture/MCU/TRIG: J300.3; also elsewhere on the board
GND: C300.1, C303.2, C304.1, C305.2, C306.2, C307.2, C308.2, J300.1, JP300.1 (A), JP302.1 (A), U300.6 (GND), U300.8 (GND), U301.2 (SDX), U301.3 (SCX), U301.6 (GND), U301.7 (GND), U302.3 (GND), U302.4 (CSB), U302.5 (CSB); also elsewhere on the board
unnamed: JP300.2 (B), R300.2, U301.1 (SDO/SA0)
unnamed: JP302.2 (B), R301.2, U302.6 (SDO)
unnamed: C303.1, U300.5 (C1)

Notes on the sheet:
Test Points
I2C Bus Pull-up Resistors
[${#}] ${TITLE}
DESIGN NOTE: IMU address: 110101 + !SDO + R/W bit Magnetometer address: 0011110 + R/W bit Barometer address: 111011 + SDO + R/W bit
Barometer
Distance Sensor
DESIGN NOTE: The Jumper can be used to change the I2C address
Magnetometer
LAYOUT NOTE: Route I2C Lines through resistors to minimise stubs
Inertial Measurement Unit
DESIGN NOTE: Logic for this pin is flipped

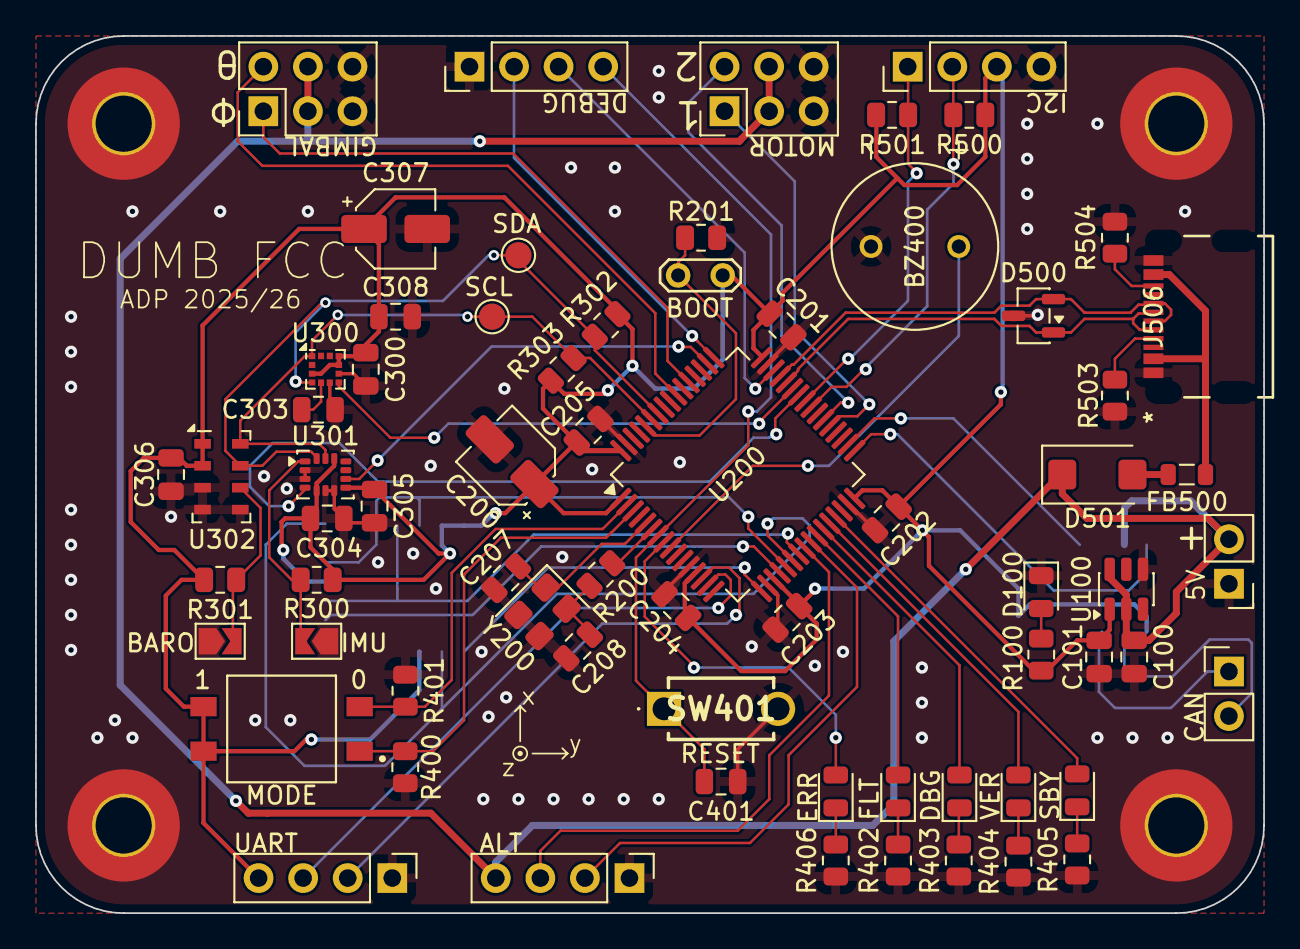
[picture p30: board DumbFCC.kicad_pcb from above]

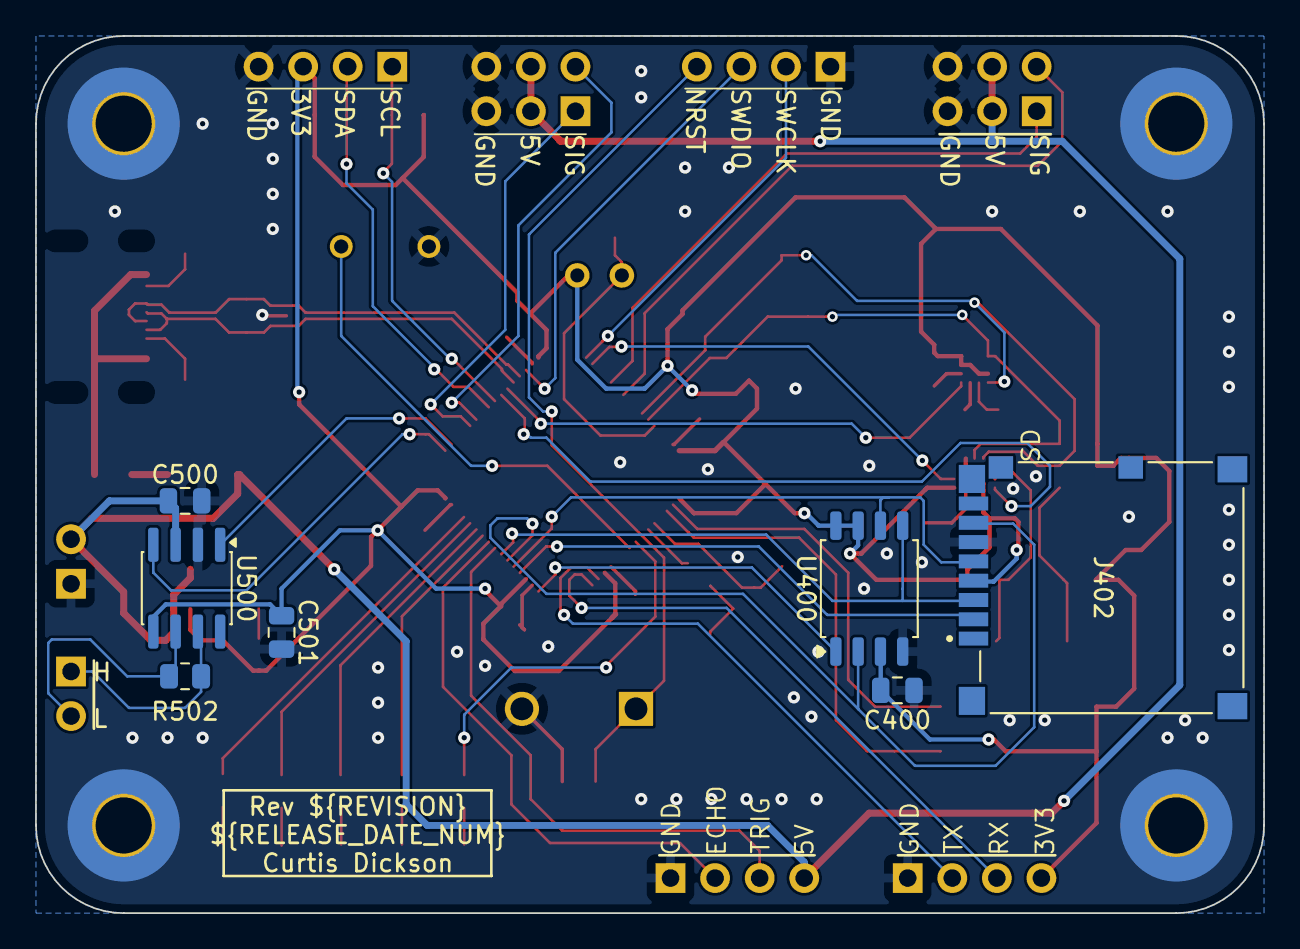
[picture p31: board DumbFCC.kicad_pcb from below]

Board: 4 copper layers, 70.0 x 50.0 mm, 79 parts (7 on the bottom side), 57 nets.

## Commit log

2026-03-13 First draft of schematic
    [Block Diagram.kicad_sch, Connections.kicad_sch, DumbFCC.kicad_pcb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]
2026-03-13 Update Outputs
    [DumbFCC-bom.csv]
2026-03-13 preliminary version of PCB layout
2026-03-13 Checked version of schematic and PCB
2026-03-13 Resolved ERC errors
    [Revision History.kicad_sch]
2026-03-13 Update Outputs (release)
    [DumbFCC-B_Mask.gbr, DumbFCC-B_Paste.gbr, DumbFCC-B_Silkscreen.gbr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]
2026-03-13 [PCB][Fixed] Fixed wrong Diode footprint and Changed TVS diode package, also changed wrong footprint of CAN transiever chip. [Changed] Changed the FLASH chip to a different model due to a stocking is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
    [Connections.kicad_sch, DumbFCC.kicad_pcb, Peripherals.kicad_sch]
2026-03-14 [pcb][changed] updated footprints that were incorrect, changed flash memory module due to stock issues
    [Connections.kicad_sch, DumbFCC.kicad_pcb, Power.kicad_sch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]
